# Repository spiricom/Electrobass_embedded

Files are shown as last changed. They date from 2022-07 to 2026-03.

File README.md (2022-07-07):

# Electrobass_embedded
Code for the three microcontrollers in the Electrobass hardware

## Changing name of an STMCube32 project 
https://community.st.com/s/question/0D53W000004Htp3SAC/change-the-name-of-the-project-in-stm32cubeide

1. Change name in `.project` file
2. Change directory name 
3. File->Import->existing project into workspace
4. click copy projects into workspace

## Adding LEAF after pull
1. right-click the leaf folder in the STMCube32IDE and go to properties (leaf->properties)
2. Under C/C++ Build->settings unclick `Exclude resource from build`
3. right-click the top level project and go to properties (project->properties)
3. Under C/C++ Build->settings->MCU GCC Compiler->Include Paths Add your leaf directory

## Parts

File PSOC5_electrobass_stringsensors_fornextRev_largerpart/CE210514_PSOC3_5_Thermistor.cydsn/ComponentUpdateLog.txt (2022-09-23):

Last Modified Date & Time: 07/15/2018 13:28:18

CE210514_PSOC3_5_Thermistor: CE210514_PSOC3_5_Thermistor.cydwr
	cy_boot [v5.20] to [v5.70]
	Em_EEPROM_Dynamic [v2.0] to [v2.10]
	LIN_Dynamic [v3.20] to [v4.0]

CE210514_PSOC3_5_Thermistor: TopDesign.cysch
	ADC [v3.20] to [v3.30]
	LCD [v2.10] to [v2.20]
	TX [v2.10] to [v2.20]
	Vhi [v2.10] to [v2.20]
	Vlow [v2.10] to [v2.20]
	Vtherm [v2.10] to [v2.20]

Last Modified Date & Time: 08/16/2022 14:56:38

CE210514_PSOC3_5_Thermistor: CE210514_PSOC3_5_Thermistor.cydwr
	cy_boot [v5.70] to [v6.10]
	Em_EEPROM_Dynamic [v2.10] to [v2.20]
	LIN_Dynamic [v4.0] to [v5.0]

CE210514_PSOC3_5_Thermistor: TopDesign.cysch
	Sleep_isr [v1.70] to [v1.71]

Last Modified Date & Time: 09/15/2022 13:51:09

CE210514_PSOC3_5_Thermistor: CE210514_PSOC3_5_Thermistor.cydwr
	LIN_Dynamic [v5.0] to [v6.0]

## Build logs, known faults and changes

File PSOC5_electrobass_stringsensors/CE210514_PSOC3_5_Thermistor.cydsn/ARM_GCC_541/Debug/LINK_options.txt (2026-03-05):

-Wl,--start-group -o "C:\\Users\\ggg88\\dev\\Electrobass_embedded\\PSOC5_electrobass_stringsensors\\CE210514_PSOC3_5_Thermistor.cydsn\\ARM_GCC_541\\Debug\\CE210514_PSOC3_5_Thermistor.elf" ".\\ARM_GCC_541\\Debug\\main.o" ".\\ARM_GCC_541\\Debug\\midi.o" ".\\ARM_GCC_541\\Debug\\oled.o" ".\\ARM_GCC_541\\Debug\\ssd1306.o" ".\\ARM_GCC_541\\Debug\\gfx.o" ".\\ARM_GCC_541\\Debug\\gfx_font.o" ".\\ARM_GCC_541\\Debug\\cyfitter_cfg.o" ".\\ARM_GCC_541\\Debug\\cymetadata.o" ".\\ARM_GCC_541\\Debug\\Cm3Start.o" ".\\ARM_GCC_541\\Debug\\CE210514_PSOC3_5_Thermistor.a" "C:\\Program\ Files\ (x86)\\Cypress\\PSoC\ Creator\\4.4\\PSoC\ Creator\\psoc\\content\\CyComponentLibrary\\CyComponentLibrary.cylib\\CapSense_CSD_v3_50\\Library\\CapSenseLibrary_GCC.a" "C:\\Program\ Files\ (x86)\\Cypress\\PSoC\ Creator\\4.4\\PSoC\ Creator\\psoc\\content\\cycomponentlibrary\\CyComponentLibrary.cylib\\CortexM3\\ARM_GCC_541\\Debug\\CyComponentLibrary.a" -mcpu=cortex-m3 -mthumb -l m -L "Generated_Source\\PSoC5" "-Wl,-Map,.\\ARM_GCC_541\\Debug/CE210514_PSOC3_5_Thermistor.map" -T "Generated_Source\\PSoC5\\cm3gcc.ld" -specs=nano.specs -Wl,--gc-sections -u_printf_float -g -ffunction-sections -finline-functions -O3 -flto -ffat-lto-objects -Wl,--end-group

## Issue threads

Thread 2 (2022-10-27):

change all leaf MB oscillators to use the distributed computing rather than block, and maybe switch oscillators to be wavetable unless synced

spiricom, 2022-10-27:

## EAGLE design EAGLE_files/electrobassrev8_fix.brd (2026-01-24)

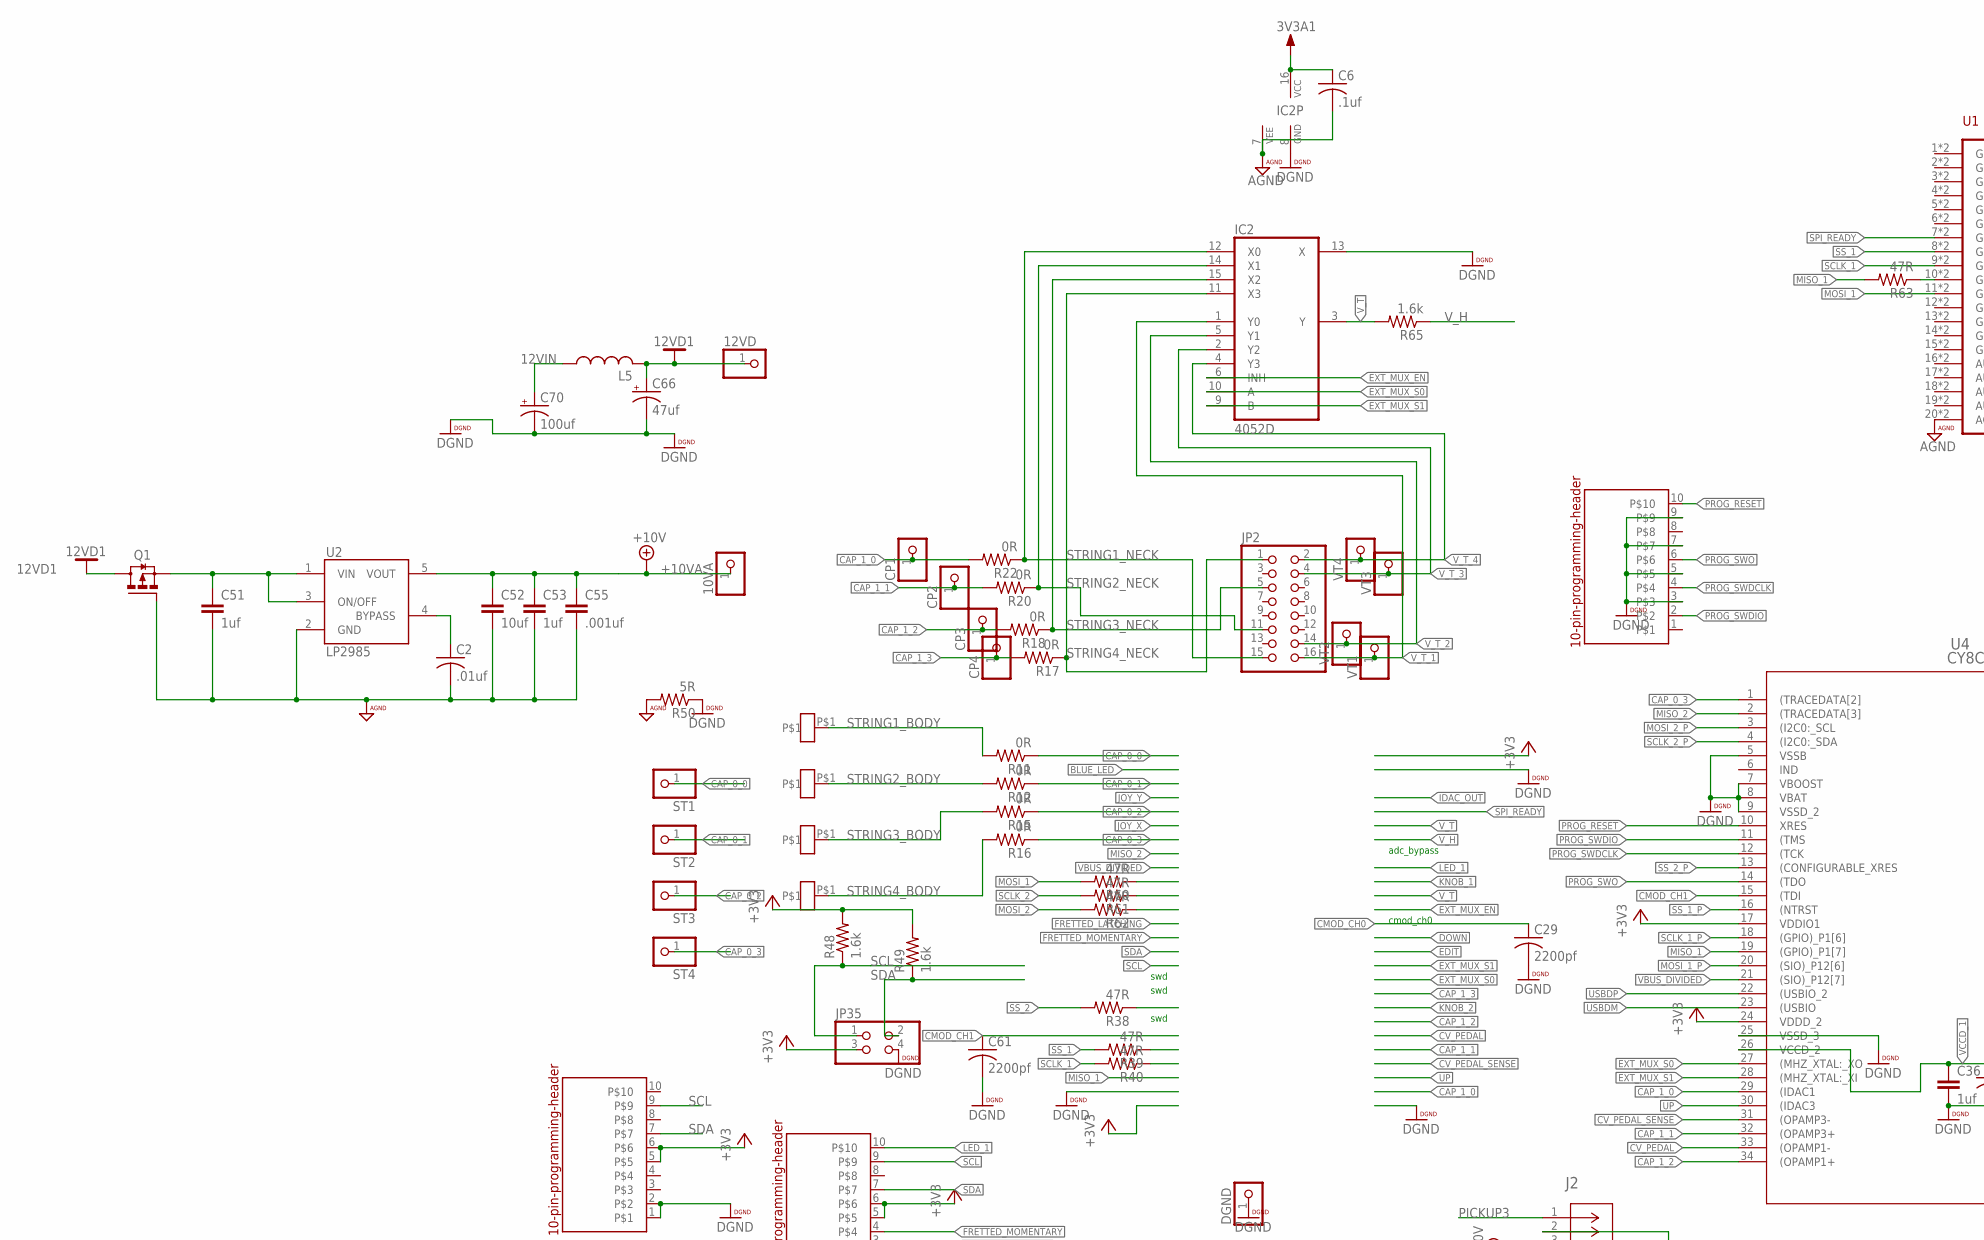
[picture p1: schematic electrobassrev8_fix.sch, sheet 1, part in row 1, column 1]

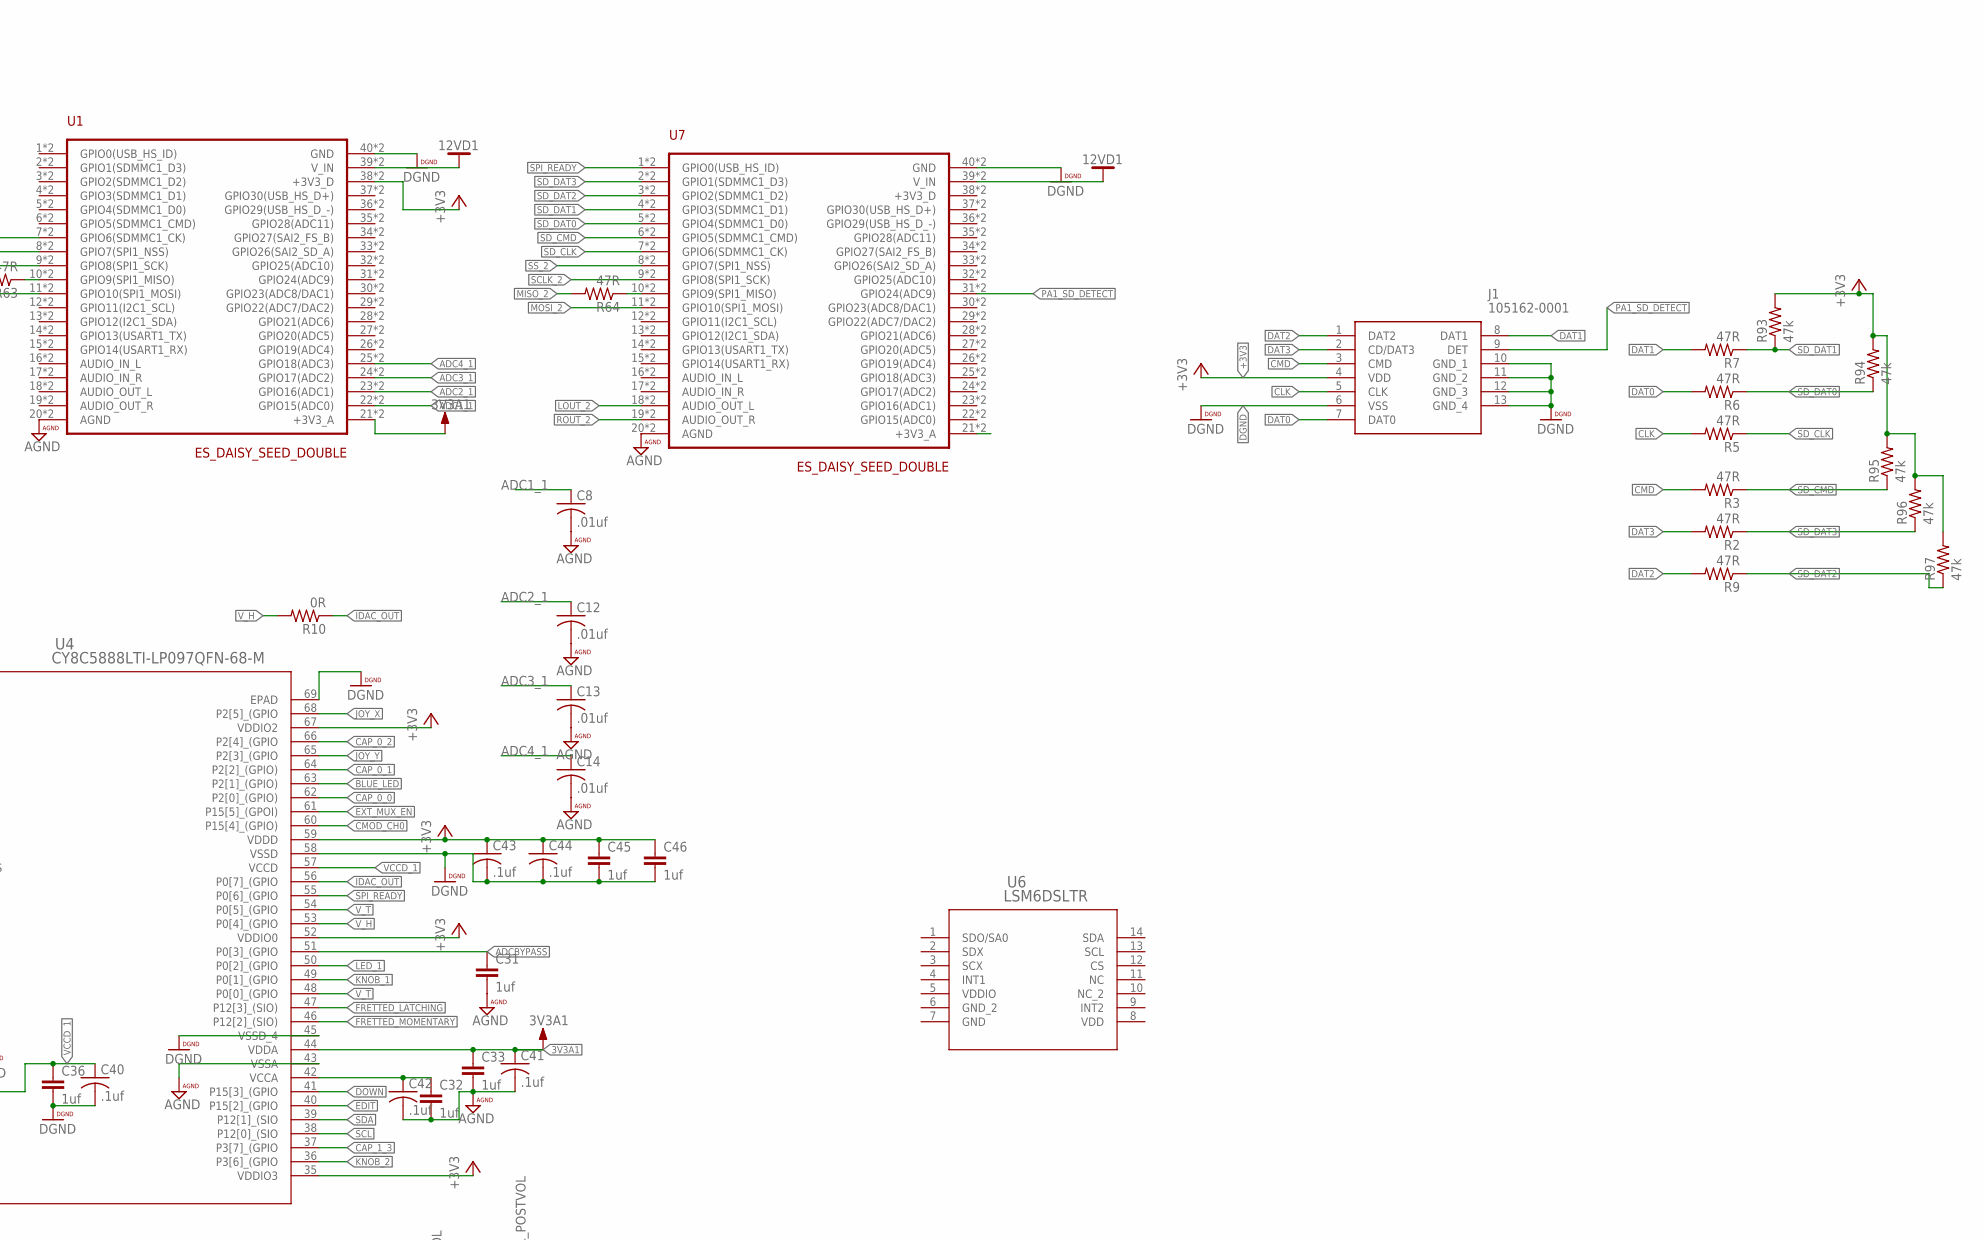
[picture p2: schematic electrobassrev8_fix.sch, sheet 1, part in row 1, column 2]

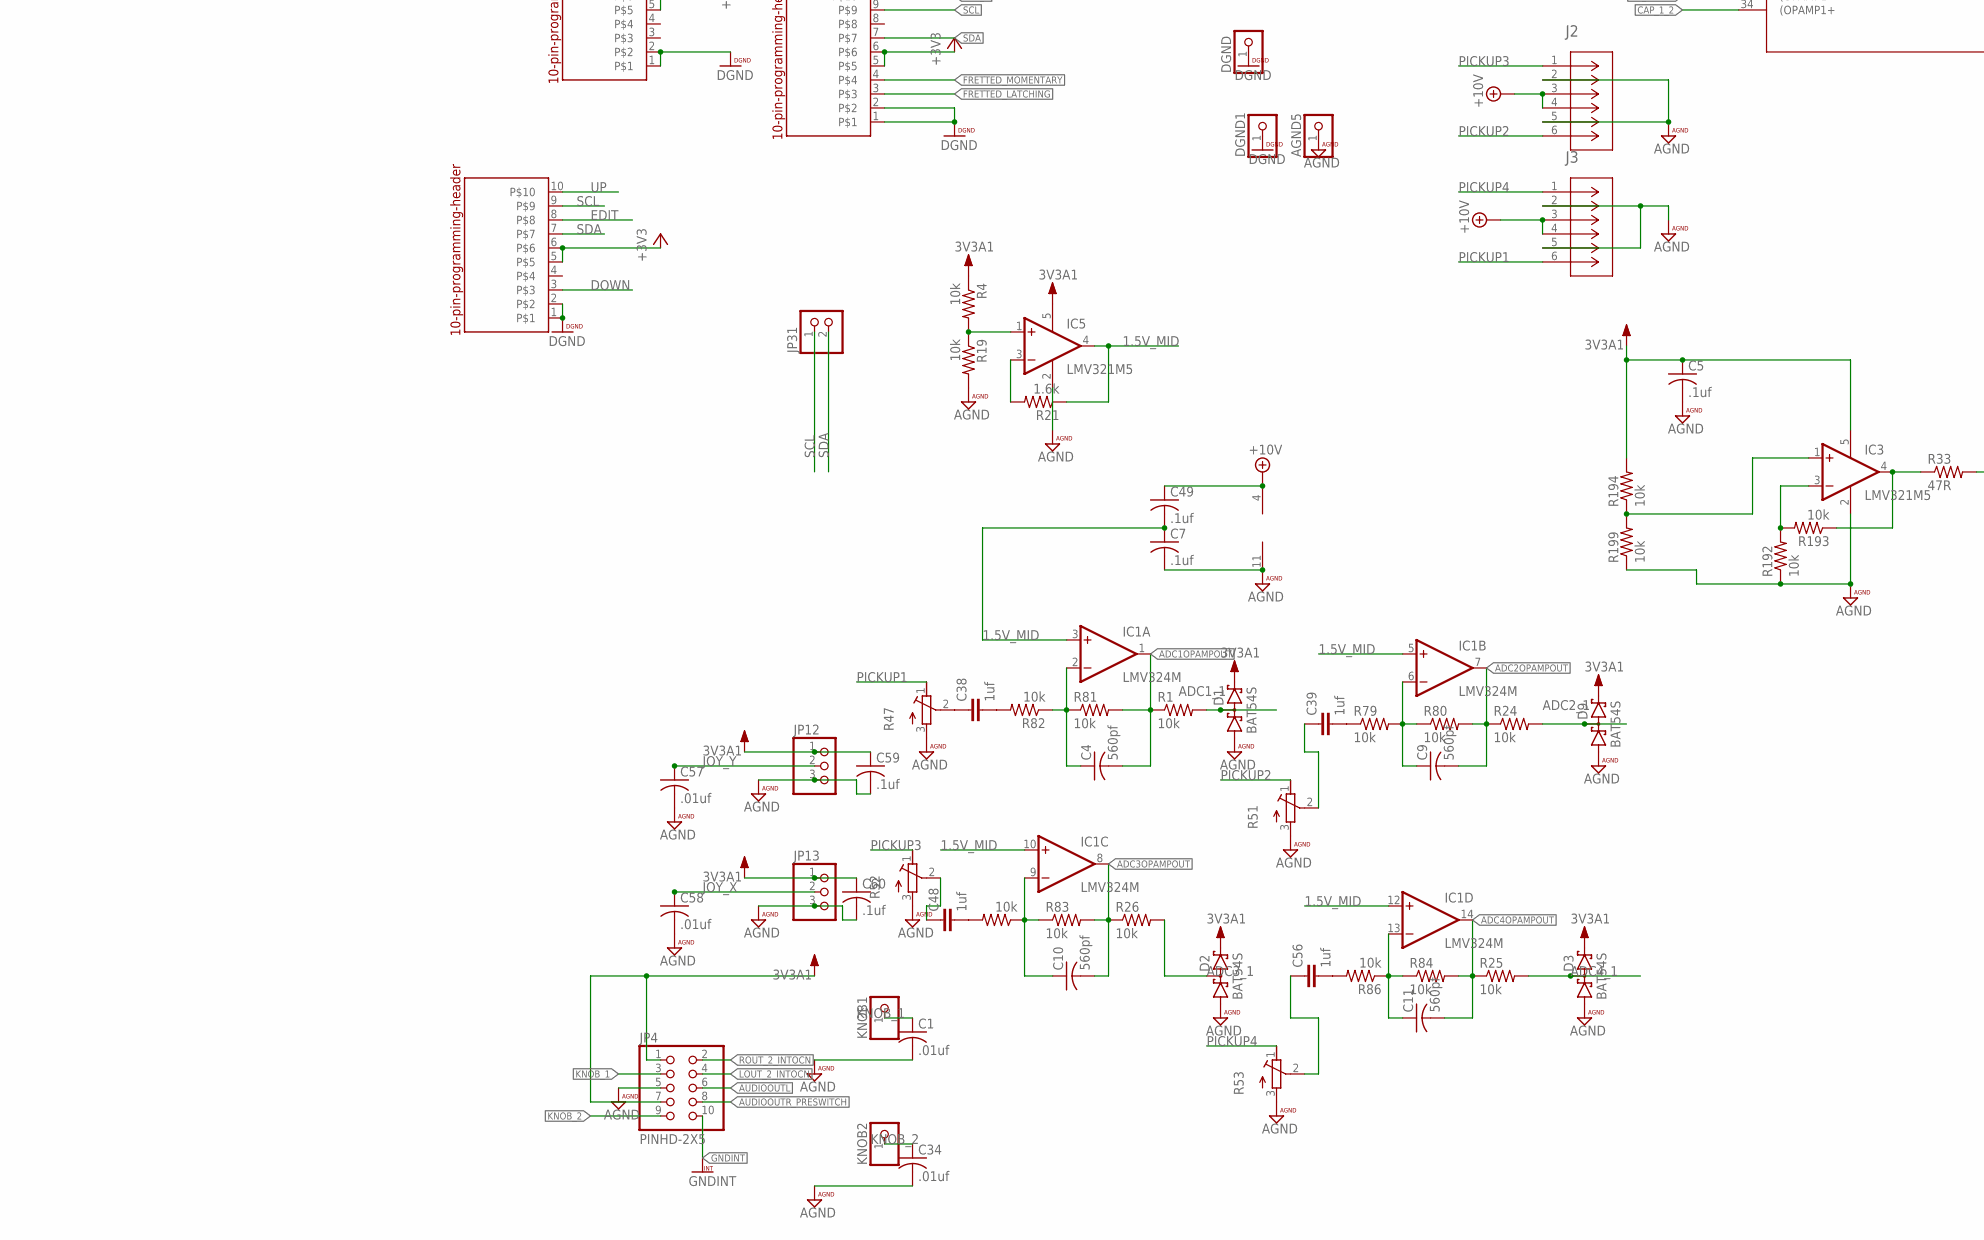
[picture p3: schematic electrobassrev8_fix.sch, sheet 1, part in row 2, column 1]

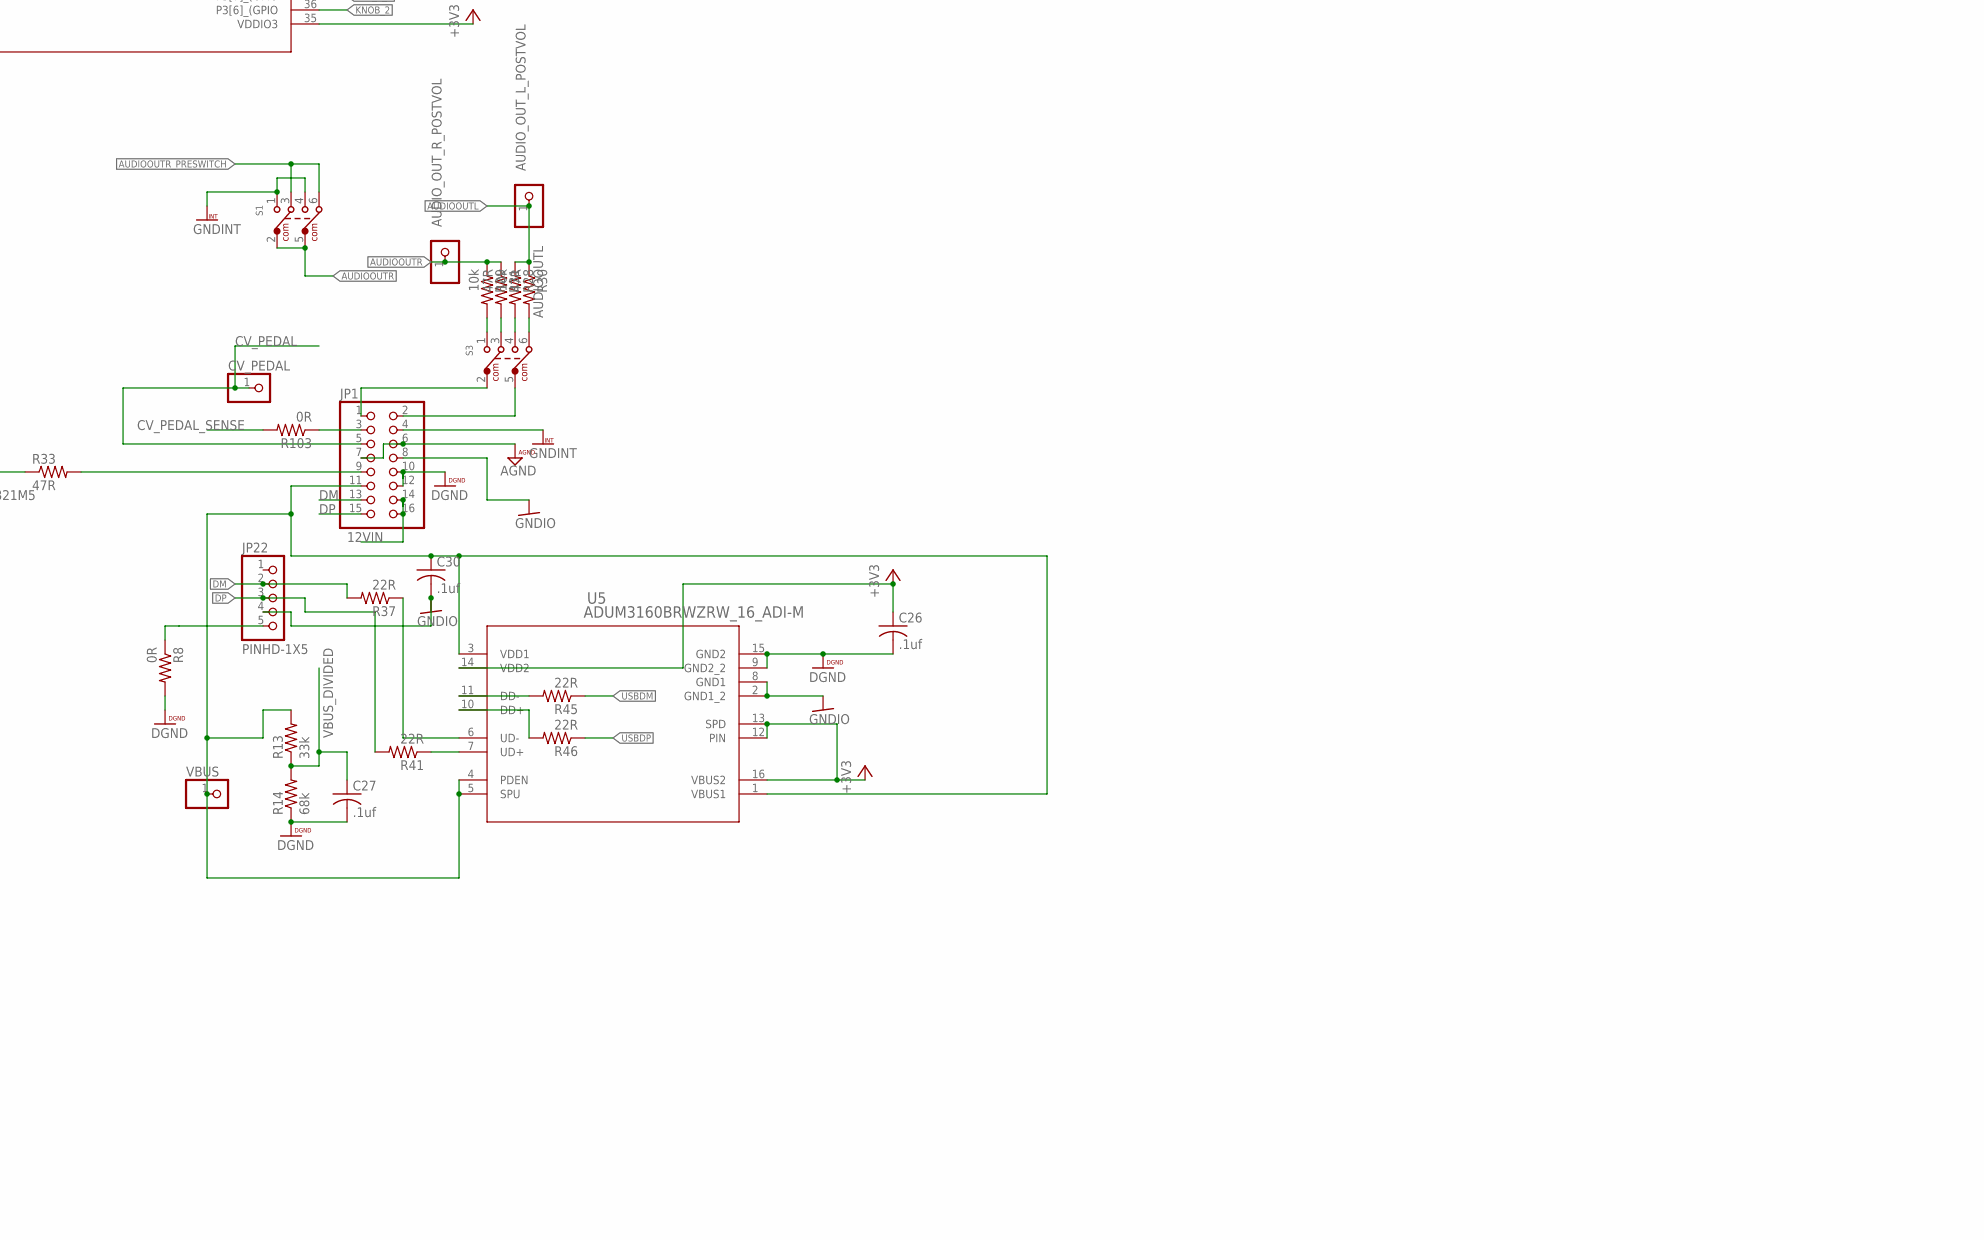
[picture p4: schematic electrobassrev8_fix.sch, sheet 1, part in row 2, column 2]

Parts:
10VA, 12VD: PINHD-1X1; 1X01; PARTNO *DNP
AGND5: PINHD-1X1; 1X01; PARTNO *DNP
AUDIO_OUT_L_POSTVOL: PINHD-1X1; 1X01; PARTNO *DNP
AUDIO_OUT_R_POSTVOL: PINHD-1X1; 1X01; PARTNO *DNP
C1, C2, C8, C12, C13, C14, C34, C57, C58: .01uf; C0603K; PARTNO CC0603KRX7R8BB103
C4, C9, C10, C11: 560pf; C0603K; PARTNO CC0603KRX7R8BB103
C5, C6, C7, C26, C27, C30, C40, C41, C42, C43, C44, C49, C59, C60: .1uf; C0603K; PARTNO CC0603KRX7R8BB104
C29, C61: 2200pf; C0603K; PARTNO CC0603KRX7R9BB222
C31, C32, C33, C36, C38, C39, C45, C46, C48, C51, C53, C56: 1uf; C0603; PARTNO UMK107BJ105KA-T
C52: 10uf; C1206K; PARTNO TMK316F106ZL-T
C55: .001uf; C0603; PARTNO CC0603JRNPO8BN102
C66: 47uf; PANASONIC_E; PARTNO EEE-1VA470P
C70: 100uf; PANASONIC_F; PARTNO UUQ1E101MCL1GS
CP1, CP2, CP3, CP4: PINHD-1X1; 1X01; PARTNO *DNP
CV_PEDAL: PINHD-1X1; 1X01; PARTNO *DNP
D1, D2, D3, D9: BAT54S; SOT23; PARTNO BAT54S-HF
DGND, DGND1: PINHD-1X1; 1X01; PARTNO *DNP
IC1: LMV324M; SO14
IC2: 4052D; SO16; PARTNO MC74HC4052ADR2G
IC3, IC5: LMV321M5; SOT23-5; PARTNO NCV20091SN3T1G
J1: 105162-0001; PARTNO 1051620001
J2, J3: SM06B-SRSS-TB(LF)(SN); CONN_SM06B-SRSS-TB_JST
JP1, JP2: PINHD-2X8; 2X08; PARTNO SBH11-PBPC-D08-ST-BK
JP4: PINHD-2X5; 2X05; PARTNO 3020-10-0100-00
JP5, JP8, JP9, JP23: 20021121; PARTNO 3221-10-0300-00
JP12, JP13: PINHD-1X3; 1X03; PARTNO *DNP
JP22: PINHD-1X5; 1X05; PARTNO *DNP
JP31: PINHD-1X2; 1X02; PARTNO *DNP
JP35: PINHD-2X2; 2X02; PARTNO *DNP
KNOB1, KNOB2: PINHD-1X1; 1X01; PARTNO *DNP
L5: L-US6000-XXX-RC; 6000-XXXX-RC; PARTNO RLB9012-100KL
Q1: DMP3099L; SUPER-SOT3; PARTNO DMP3125L-7
R1, R24, R25, R26, R80, R81, R83, R84: 10k; R0603; PARTNO ESR03EZPF2002
R2, R3, R5, R6, R7, R9, R30, R31, R33, R38, R39, R40, R60, R61, R62, R63, R64: 47R; R0603; PARTNO RC0603JR-0747RL
R4, R19, R28, R29, R79, R82, R85, R86, R192, R193, R194, R199: 10k; R0603; PARTNO ESR03EZPF1002
R8, R10, R11, R12, R15, R16, R17, R18, R20, R22, R103: 0R; R0603; PARTNO CRCW06030000Z0EAHP
R13: 33k; R0603; PARTNO ESR03EZPJ333
R14: 68k; R0603; PARTNO CRCW060368K0FKEAHP
R21, R48, R49, R65: 1.6k; R0603; PARTNO ESR03EZPJ152
R37, R41, R45, R46: 22R; R0603; PARTNO RC0603JR-0747RL
R47, R51, R52, R53: R-TRIMM3314J; RTRIM3314J
R50: 5R; R0603; PARTNO CRCW06030000Z0EAHP
R93, R94, R95, R96, R97: 47k; R0603; PARTNO ESR03EZPJ333
S1, S3: 452404020202; PARTNO 452404020202
ST1, ST2, ST3, ST4: PINHD-1X1; 1X01; PARTNO *DNP
U1, U7: ES_DAISY_SEED_DOUBLE; PARTNO *DNP
U2: LP2985; SOT25; PARTNO LP2985-10DBVR
U4: CY8C5888LTI-LP097QFN-68-M; QFN-68-M
U5: ADUM3160BRWZRW_16_ADI-M; RW_16_ADI-M
U6: LSM6DSLTR; QFN_6DSLTR_STM
U$15, U$16, U$68, U$69: STRING_HOLDER; PARTNO *DNP
VBUS: PINHD-1X1; 1X01; PARTNO *DNP
VT1, VT2, VT3, VT4: PINHD-1X1; 1X01; PARTNO *DNP

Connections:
1.5V_MID: C7.1, C49.2, IC1.3 (+IN), IC1.5 (+IN), IC1.10 (+IN), IC1.12 (+IN), IC5.4 (OUT), R21.1
3V3A1: C5.1, C6.1, C33.1, C41.1, C59.1, C60.1, D1.2 (C2), D2.2 (C2), D3.2 (C2), D9.2 (C2), IC2.16 (VCC), IC3.5 (V+), IC5.5 (V+), JP4.1, JP4.7, JP12.1, JP13.1, R4.1, R194.2, U1.21 (+3V3_A), U1.B21 (+3V3_A), U4.44 (VDDA)
3V3FORPEDAL: JP1.9, R33.2
12VD1: 12VD.1, C66.+, L5.2, Q1.3 (D), U1.39 (V_IN), U1.B39 (V_IN), U7.39 (V_IN), U7.B39 (V_IN); also elsewhere on the board
12VIN: C70.+, JP1.14, JP1.16, L5.1
+3V3: C26.1, C43.1, C44.1, C45.1, C46.1, J1.4 (VDD), JP8.5, JP8.6, JP9.5, JP9.6, JP23.5, JP23.6, JP35.3, R48.2, R49.2, R93.2, R94.2, R95.2, R96.2, R97.2, U1.38 (+3V3_D), U1.B38 (+3V3_D), U4.17 (VDDIO1), U4.24 (VDDD_2), U4.35 (VDDIO3), U4.52 (VDDIO0), U4.59 (VDDD), U4.67 (VDDIO2), U5.12 (PIN), U5.13 (SPD), U5.14 (VDD2), U5.16 (VBUS2)
+10V: 10VA.1, C49.1, C52.1, C53.1, C55.1, IC1.4 (V+), J2.3, J2.4, J3.3, J3.4, U2.5 (VOUT)
ADC1OPAMPOUT: C4.2, IC1.1 (OUT), R1.1, R81.2
ADC1_1: C8.1, D1.3 (C1A2), R1.2, U1.22 (GPIO15(ADC0)), U1.B22 (GPIO15(ADC0))
ADC2OPAMPOUT: C9.2, IC1.7 (OUT), R24.1, R80.2
ADC2_1: C12.1, D9.3 (C1A2), R24.2, U1.23 (GPIO16(ADC1)), U1.B23 (GPIO16(ADC1))
ADC3OPAMPOUT: C10.2, IC1.8 (OUT), R26.1, R83.2
ADC3_1: C13.1, D2.3 (C1A2), R26.2, U1.24 (GPIO17(ADC2)), U1.B24 (GPIO17(ADC2))
ADC4OPAMPOUT: C11.2, IC1.14 (OUT), R25.1, R84.2
ADC4_1: C14.1, D3.3 (C1A2), R25.2, U1.25 (GPIO18(ADC3)), U1.B25 (GPIO18(ADC3))
ADCBYPASS: C31.1, U4.51 (P0[3]_(GPIO)
AGND: AGND5.1, C1.2, C2.2, C5.2, C6.2, C7.2, C8.2, C12.2, C13.2, C14.2, C31.2, C32.2, C33.2, C34.2, C41.2, C42.2, C51.2, C52.2, C53.2, C55.2, C57.2, C58.2, C59.2, C60.2, D1.1 (A1), D2.1 (A1), D3.1 (A1), D9.1 (A1), IC1.11 (V-), IC2.7 (VEE), IC3.2 (V-), IC5.2 (V-), J2.2, J2.5, J3.2, J3.5, JP1.6, JP1.7, JP4.5, JP12.3, JP13.3, Q1.1 (G), R19.2, R47.3 (A), R50.2, R51.3 (A), R52.3 (A), R53.3 (A), R192.1, R199.1, U1.20 (AGND), U1.B20 (AGND), U2.2 (GND), U4.43 (VSSA), U7.20 (AGND), U7.B20 (AGND); also elsewhere on the board
AUDIOOUTL: AUDIO_OUT_L_POSTVOL.1, JP4.6, R28.1, R30.1
AUDIOOUTR: AUDIO_OUT_R_POSTVOL.1, R29.1, R31.1, S1.2 (COM), S1.5 (COM1)
AUDIOOUTR_PRESWITCH: JP4.8, S1.3, S1.6
BLUE_LED: U4.63 (P2[1]_(GPIO))
BYPASS: C2.1, U2.4 (BYPASS)
CAP_0_0: R11.1, ST1.1, U4.62 (P2[0]_(GPIO))
CAP_0_1: R12.1, ST2.1, U4.64 (P2[2]_(GPIO))
CAP_0_2: R15.1, ST3.1, U4.66 (P2[4]_(GPIO)
CAP_0_3: R16.1, ST4.1, U4.1 ((TRACEDATA[2])
CAP_1_0: CP1.1, R22.2, U4.29 ((IDAC1)
CAP_1_1: CP2.1, R20.2, U4.32 ((OPAMP3+)
CAP_1_2: CP3.1, R18.2, U4.34 ((OPAMP1+)
CAP_1_3: CP4.1, R17.2, U4.37 (P3[7]_(GPIO)
CLK: J1.5 (CLK), R5.2
CMD: J1.3 (CMD), R3.2
CMOD_CH0: C29.1, U4.60 (P15[4]_(GPIO))
CMOD_CH1: C61.1, U4.15 ((TDI)
CV_PEDAL: CV_PEDAL.1, JP1.5, U4.33 ((OPAMP1-)
CV_PEDAL_SENSE: R103.2, U4.31 ((OPAMP3-)
DAT0: J1.7 (DAT0), R6.2
DAT1: J1.8 (DAT1), R7.2
DAT2: J1.1 (DAT2), R9.2
DAT3: J1.2 (CD/DAT3), R2.2
DGND: C26.2, C27.2, C29.2, C36.2, C40.2, C43.2, C44.2, C45.2, C46.2, C61.2, C66.-, C70.-, DGND.1, DGND1.1, IC2.8 (GND), IC2.13 (X), J1.6 (VSS), J1.10 (GND_1), J1.11 (GND_2), J1.12 (GND_3), J1.13 (GND_4), JP1.10, JP1.12, JP5.3, JP5.5, JP5.7, JP5.9, JP8.1, JP8.2, JP9.1, JP9.2, JP23.1, JP23.2, JP35.4, R8.2, R14.1, R50.1, U1.40 (GND), U1.B40 (GND), U4.5 (VSSB), U4.7 (VBOOST), U4.8 (VBAT), U4.9 (VSSD_2), U4.25 (VSSD_3), U4.45 (VSSD_4), U4.58 (VSSD), U4.69 (EPAD), U5.9 (GND2_2), U5.15 (GND2), U7.40 (GND), U7.B40 (GND)
DM: JP1.13, JP22.2, R37.2
DOWN: JP9.3, U4.41 (P15[3]_(GPIO)
DP: JP1.15, JP22.3, R41.2
EDIT: JP9.8, U4.40 (P15[2]_(GPIO)
EXT_MUX_EN: IC2.6 (INH), U4.61 (P15[5]_(GPOI))
EXT_MUX_S0: IC2.10 (A), U4.27 ((MHZ_XTAL:_XO)
EXT_MUX_S1: IC2.9 (B), U4.28 ((MHZ_XTAL:_XI)
FRETTED_LATCHING: JP23.3, U4.47 (P12[3]_(SIO))
FRETTED_MOMENTARY: JP23.4, U4.46 (P12[2]_(SIO))
GND: U6.7 (GND)
GNDINT: JP1.4, JP4.10; also elsewhere on the board
GNDIO: C30.2, JP1.8, JP22.4, U5.2 (GND1_2), U5.8 (GND1)
GND_2: U6.6 (GND_2)
IDAC_OUT: R10.1, U4.56 (P0[7]_(GPIO)
JOY_X: C58.1, JP13.2, U4.68 (P2[5]_(GPIO)
JOY_Y: C57.1, JP12.2, U4.65 (P2[3]_(GPIO)
KNOB_1: C1.1, JP4.3, KNOB1.1, U4.49 (P0[1]_(GPIO)
KNOB_2: C34.1, JP4.9, KNOB2.1, U4.36 (P3[6]_(GPIO)
LED_1: JP23.10, U4.50 (P0[2]_(GPIO)
LOUT_2: U7.18 (AUDIO_OUT_L), U7.B18 (AUDIO_OUT_L); also elsewhere on the board
LOUT_2_INTOCN: JP4.4; also elsewhere on the board
MISO_1: R63.2, U4.19 ((GPIO)_P1[7])
MISO_1_P: R63.1, U1.10 (GPIO9(SPI1_MISO)), U1.B10 (GPIO9(SPI1_MISO))
MISO_2: R64.2, U4.2 ((TRACEDATA[3])
MISO_2_P: R64.1, U7.10 (GPIO9(SPI1_MISO)), U7.B10 (GPIO9(SPI1_MISO))
MOSI_1: R60.2, U1.11 (GPIO10(SPI1_MOSI)), U1.B11 (GPIO10(SPI1_MOSI))
MOSI_1_P: R60.1, U4.20 ((SIO)_P12[6])
MOSI_2: R62.2, U7.11 (GPIO10(SPI1_MOSI)), U7.B11 (GPIO10(SPI1_MOSI))
MOSI_2_P: R62.1, U4.3 ((I2C0:_SCL)
unnamed: JP1.3, R103.1
unnamed: R29.2, S3.1
unnamed: R28.2, S3.4
unnamed: JP1.1, S3.2 (COM)
unnamed: JP1.2, S3.5 (COM1)
unnamed: R31.2, S3.3
unnamed: R30.2, S3.6
unnamed: IC3.4 (OUT), R33.1, R193.1
unnamed: JP22.5, R8.1
unnamed: C38.2, R82.2
unnamed: S1.1, S1.4
unnamed: C39.2, R79.1
unnamed: R37.1, U5.6 (UD-)
unnamed: R41.1, U5.7 (UD+)
unnamed: C48.2, R85.2
unnamed: C56.2, R86.2
unnamed: C4.1, IC1.2 (-IN), R81.1, R82.1
unnamed: C9.1, IC1.6 (-IN), R79.2, R80.1
unnamed: C11.1, IC1.13 (-IN), R84.1, R86.1
unnamed: C10.1, IC1.9 (-IN), R83.1, R85.1
unnamed: IC5.3 (-IN), R21.2
unnamed: IC5.1 (+IN), R4.2, R19.1
unnamed: U7.21 (+3V3_A), U7.B21 (+3V3_A)
unnamed: C48.1, R52.2 (S)
unnamed: R45.2, U5.11 (DD-)
unnamed: R46.2, U5.10 (DD+)
unnamed: C56.1, R53.2 (S)
unnamed: C38.1, R47.2 (S)
unnamed: C39.1, R51.2 (S)
unnamed: C51.1, Q1.2 (S), U2.1 (VIN), U2.3 (ON/OFF)
unnamed: IC3.3 (-IN), R192.2, R193.2
unnamed: IC3.1 (+IN), R194.1, R199.2
PA1_SD_DETECT: J1.9 (DET), U7.31 (GPIO24(ADC9)), U7.B31 (GPIO24(ADC9))
PICKUP1: J3.6, R47.1 (E)
PICKUP2: J2.6, R51.1 (E)
PICKUP3: J2.1, R52.1 (E)
PICKUP4: J3.1, R53.1 (E)
PROG_RESET: JP5.10, U4.10 (XRES)
PROG_SWDCLK: JP5.4, U4.12 ((TCK)
PROG_SWDIO: JP5.2, U4.11 ((TMS)
PROG_SWO: JP5.6, U4.14 ((TDO)
ROUT_2: U7.19 (AUDIO_OUT_R), U7.B19 (AUDIO_OUT_R); also elsewhere on the board
ROUT_2_INTOCN: JP4.2; also elsewhere on the board
SCL: JP8.9, JP9.9, JP23.9, JP31.1, JP35.1, R48.1, U4.38 (P12[0]_(SIO)
SCLK_1: R40.2, U1.9 (GPIO8(SPI1_SCK)), U1.B9 (GPIO8(SPI1_SCK))
SCLK_1_P: R40.1, U4.18 ((GPIO)_P1[6])
SCLK_2: R61.2, U7.9 (GPIO8(SPI1_SCK)), U7.B9 (GPIO8(SPI1_SCK))
SCLK_2_P: R61.1, U4.4 ((I2C0:_SDA)
SDA: JP8.7, JP9.7, JP23.7, JP31.2, JP35.2, R49.1, U4.39 (P12[1]_(SIO)
SD_CLK: R5.1, U7.7 (GPIO6(SDMMC1_CK)), U7.B7 (GPIO6(SDMMC1_CK))
SD_CMD: R3.1, R95.1, U7.6 (GPIO5(SDMMC1_CMD)), U7.B6 (GPIO5(SDMMC1_CMD))
SD_DAT0: R6.1, R94.1, U7.5 (GPIO4(SDMMC1_D0)), U7.B5 (GPIO4(SDMMC1_D0))
SD_DAT1: R7.1, R93.1, U7.4 (GPIO3(SDMMC1_D1)), U7.B4 (GPIO3(SDMMC1_D1))
SD_DAT2: R9.1, R97.1, U7.3 (GPIO2(SDMMC1_D2)), U7.B3 (GPIO2(SDMMC1_D2))
SD_DAT3: R2.1, R96.1, U7.2 (GPIO1(SDMMC1_D3)), U7.B2 (GPIO1(SDMMC1_D3))
SPI_READY: U1.7 (GPIO6(SDMMC1_CK)), U1.B7 (GPIO6(SDMMC1_CK)), U4.55 (P0[6]_(GPIO), U7.1 (GPIO0(USB_HS_ID)), U7.B1 (GPIO0(USB_HS_ID))
SS_1: R39.2, U1.8 (GPIO7(SPI1_NSS)), U1.B8 (GPIO7(SPI1_NSS))
SS_1_P: R39.1, U4.16 ((NTRST)
SS_2: R38.2, U7.8 (GPIO7(SPI1_NSS)), U7.B8 (GPIO7(SPI1_NSS))
SS_2_P: R38.1, U4.13 ((CONFIGURABLE_XRES)
STRING1_BODY: R11.2, U$16.P$1
STRING1_NECK: IC2.12 (X0), JP2.15, R22.1
STRING2_BODY: R12.2, U$15.P$1
STRING2_NECK: IC2.14 (X1), JP2.11, R20.1
STRING3_BODY: R15.2, U$68.P$1
STRING3_NECK: IC2.15 (X2), JP2.5, R18.1
STRING4_BODY: R16.2, U$69.P$1
STRING4_NECK: IC2.11 (X3), JP2.1, R17.1
UP: JP9.10, U4.30 ((IDAC3)
USBDM: R45.1, U4.23 ((USBIO)
USBDP: R46.1, U4.22 ((USBIO_2)
VBUS: C30.1, JP1.11, R13.2, U5.1 (VBUS1), U5.3 (VDD1), U5.4 (PDEN), U5.5 (SPU), VBUS.1
VBUS_DIVIDED: C27.1, R13.1, R14.2, U4.21 ((SIO)_P12[7])
VCCA_1: C32.1, C42.1, U4.42 (VCCA)
VCCD_1: C36.1, C40.1, U4.26 (VCCD_2), U4.57 (VCCD)
VDD: U6.8 (VDD)
VDDIO: U6.5 (VDDIO)
V_H: R10.2, R65.1, U4.53 (P0[4]_(GPIO)
V_T: IC2.3 (Y), R65.2, U4.48 (P0[0]_(GPIO), U4.54 (P0[5]_(GPIO)
V_T_1: IC2.1 (Y0), JP2.16, VT1.1
V_T_2: IC2.5 (Y1), JP2.14, VT2.1
V_T_3: IC2.2 (Y2), JP2.4, VT3.1
V_T_4: IC2.4 (Y3), JP2.2, VT4.1

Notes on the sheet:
+10VA
cmod_ch0
swd
adc_bypass

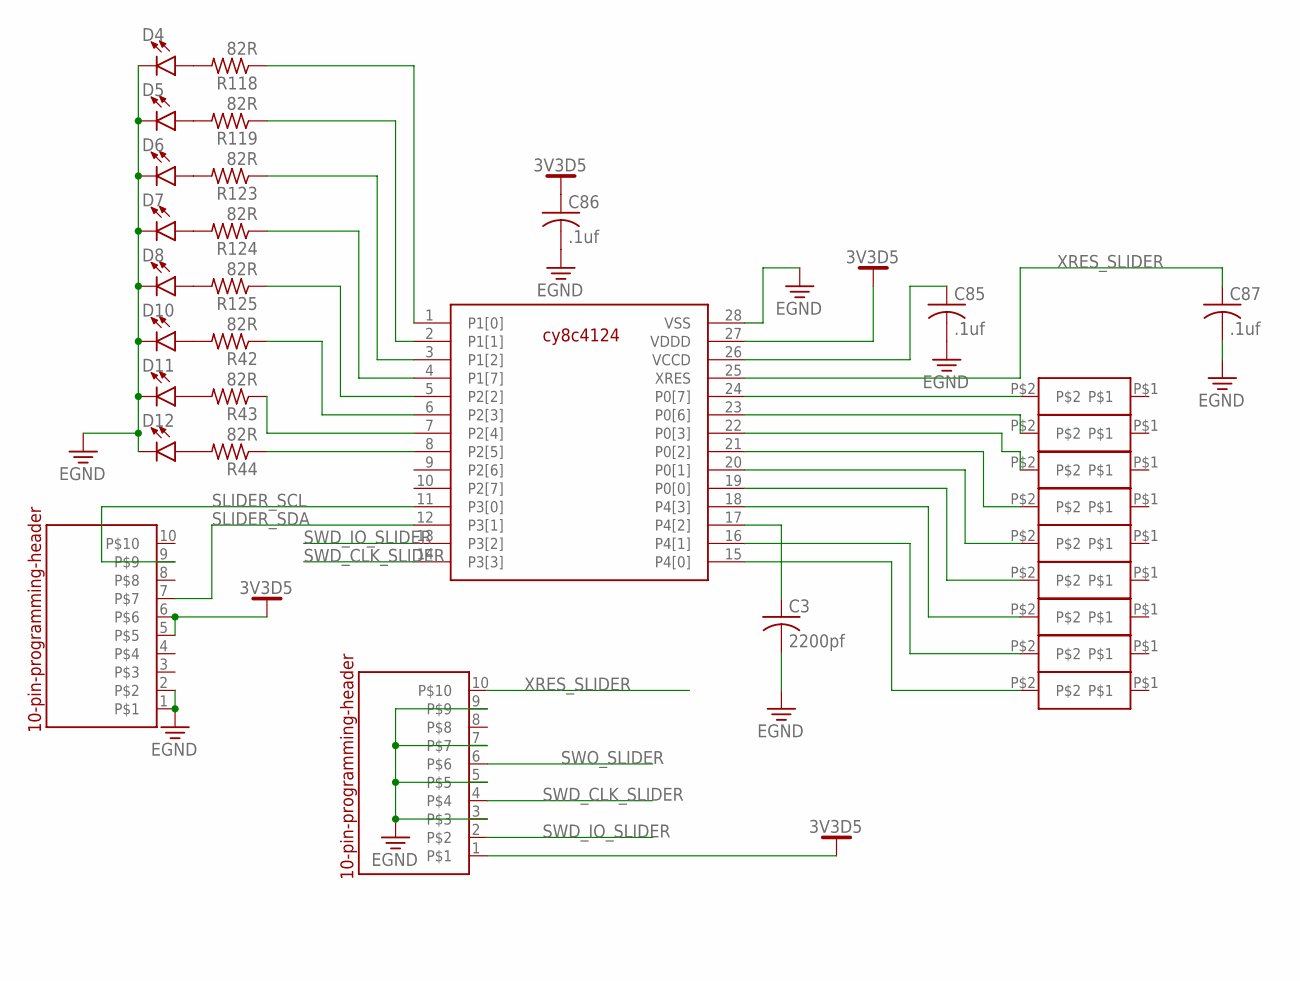
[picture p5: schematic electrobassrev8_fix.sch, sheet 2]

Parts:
C3: 2200pf; C0603K; PARTNO CC0603KRX7R9BB222
C85, C86, C87: .1uf; C0603K; PARTNO CC0603KRX7R8BB104
D4, D5, D6, D7, D8, D10, D11, D12: LED1206-BOTTOM; LED-1206-BOTTOM; PARTNO IN-S124BRA
IC18: CY8C4124; SSOP28; PARTNO CY8C4124PVI-432
JP6, JP34: 20021121; PARTNO 3221-10-0300-00
R42, R43, R44, R118, R119, R123, R124, R125: 82R; R0603; PARTNO RC0603JR-0782RL
U$1, U$5, U$11, U$12, U$13, U$14, U$18, U$19, U$20: SLIDER_SEGMENT; SLIDERS_SLIDER-SEGMENT3; PARTNO *DNP

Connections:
3V3D5: C86.1, IC18.27 (VDDD), JP6.5, JP6.6, JP34.1
EGND: C3.2, C85.2, C86.2, C87.2, D4.C, D5.C, D6.C, D7.C, D8.C, D10.C, D11.C, D12.C, IC18.28 (VSS), JP6.1, JP6.2, JP34.3, JP34.5, JP34.7, JP34.9
unnamed: D4.A, R118.2
unnamed: D5.A, R119.2
unnamed: D6.A, R123.2
unnamed: D7.A, R124.2
unnamed: D8.A, R125.2
unnamed: D10.A, R42.2
unnamed: D11.A, R43.2
unnamed: D12.A, R44.2
unnamed: IC18.8 (P2[5]), R44.1
unnamed: IC18.7 (P2[4]), R43.1
unnamed: IC18.6 (P2[3]), R42.1
unnamed: IC18.15 (P4[0]), U$20.P$2
unnamed: IC18.19 (P0[0]), U$14.P$2
unnamed: IC18.20 (P0[1]), U$13.P$2
unnamed: IC18.21 (P0[2]), U$12.P$2
unnamed: IC18.22 (P0[3]), U$11.P$2
unnamed: IC18.24 (P0[7]), U$1.P$2
unnamed: IC18.16 (P4[1]), U$19.P$2
unnamed: IC18.23 (P0[6]), U$5.P$2
unnamed: IC18.18 (P4[3]), U$18.P$2
unnamed: C85.1, IC18.26 (VCCD)
unnamed: IC18.1 (P1[0]), R118.1
unnamed: C3.1, IC18.17 (P4[2])
unnamed: IC18.2 (P1[1]), R119.1
unnamed: IC18.3 (P1[2]), R123.1
unnamed: IC18.4 (P1[7]), R124.1
unnamed: IC18.5 (P2[2]), R125.1
SLIDER_SCL: IC18.11 (P3[0]), JP6.9
SLIDER_SDA: IC18.12 (P3[1]), JP6.7
SWD_CLK_SLIDER: IC18.14 (P3[3]), JP34.4
SWD_IO_SLIDER: IC18.13 (P3[2]), JP34.2
SWO_SLIDER: JP34.6
XRES_SLIDER: C87.1, IC18.25 (XRES), JP34.10

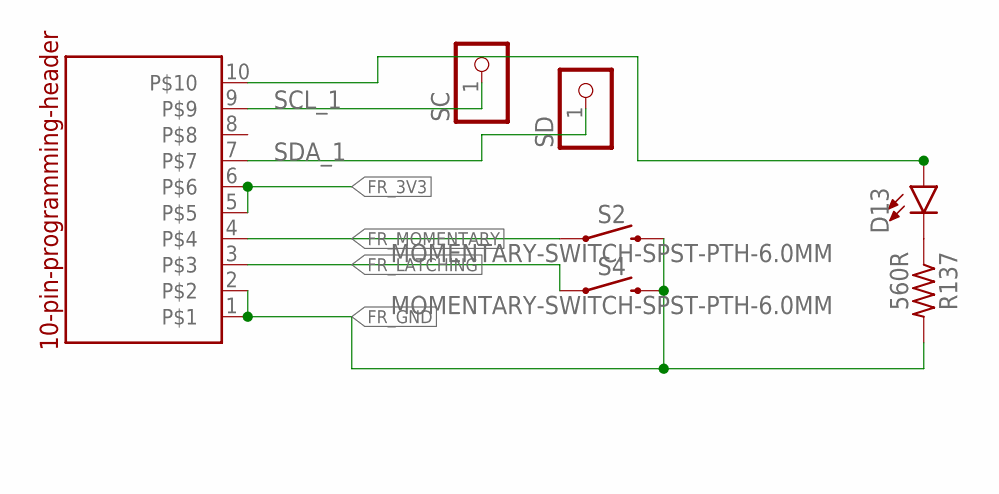
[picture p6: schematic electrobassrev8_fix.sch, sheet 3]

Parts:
D13: LED1206-BOTTOM; LED-1206-BOTTOM; PARTNO IN-S124BRA
JP24: 20021121; PARTNO 3221-10-0300-00
R137: 560R; R0603; PARTNO ESR03EZPF5600
S2, S4: MOMENTARY-SWITCH-SPST-PTH-6.0MM; TACTILE_SWITCH_PTH_6.0MM; PARTNO TL1105SPF160Q
SC: PINHD-1X1; 1X01; PARTNO *DNP
SD: PINHD-1X1; 1X01; PARTNO *DNP

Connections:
FR_3V3: JP24.5, JP24.6
FR_GND: JP24.1, JP24.2, R137.2, S2.3 (2), S4.3 (2)
FR_LATCHING: JP24.3, S4.1
FR_MOMENTARY: JP24.4, S2.1
unnamed: D13.A, JP24.10
unnamed: D13.C, R137.1
SCL_1: JP24.9, SC.1
SDA_1: JP24.7, SD.1

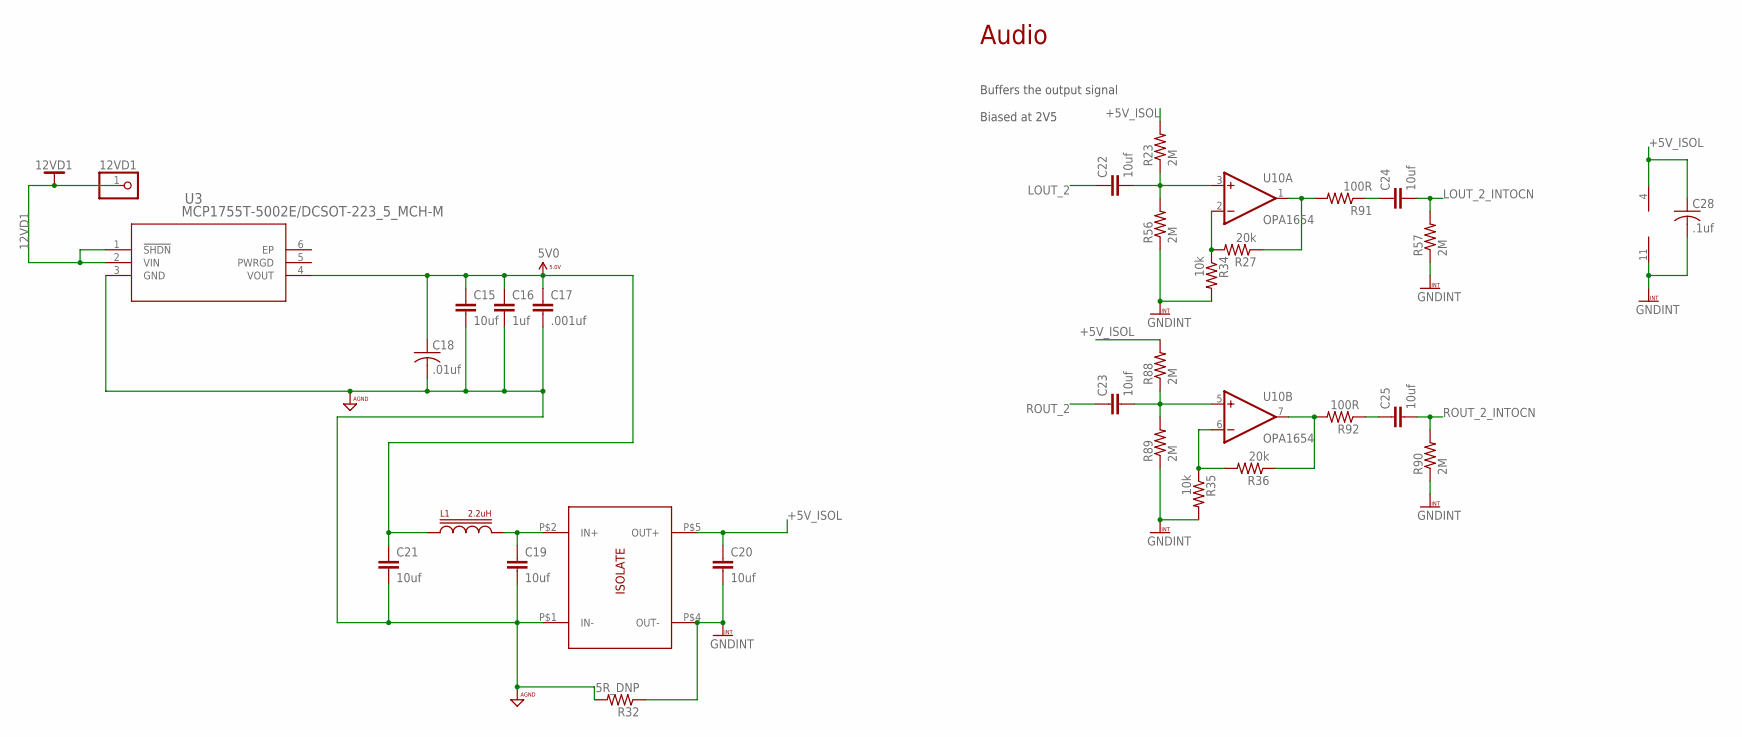
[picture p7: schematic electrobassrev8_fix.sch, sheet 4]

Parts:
12VD1: PINHD-1X1; 1X01; PARTNO *DNP
C15, C19, C20, C21, C22, C23, C24, C25: 10uf; C1206K; PARTNO TMK316F106ZL-T
C16: 1uf; C0603; PARTNO UMK107BJ105KA-T
C17: .001uf; C0603; PARTNO CC0603JRNPO8BN102
C18: .01uf; C0603K; PARTNO CC0603KRX7R8BB103
C28: .1uf; C0603K; PARTNO CC0603KRX7R8BB104
L1: 2.2uH; BOURNS_SRP2010
R23, R56, R57, R88, R89, R90: 2M; R0603
R27, R36: 20k; R0603; PARTNO ESR03EZPF1002
R32: 5R_DNP; R0603; PARTNO CRCW06030000Z0EAHP
R34, R35: 10k; R0603; PARTNO ESR03EZPF1002
R91, R92: 100R; R0603
U3: MCP1755T-5002E/DCSOT-223_5_MCH-M; SOT-223_5_MCH-M
U10: OPA1654; TSSOP-14
U$9: POWER_ISOLATE; XP_POWER_ISEXXXXA

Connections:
5V0: C15.1, C16.1, C17.1, C18.1, C21.1, L1.P$1, U3.4 (VOUT)
12VD1: 12VD1.1, U3.1 (!SHDN), U3.2 (VIN); also elsewhere on the board
+5V_ISOL: C20.1, C28.1, R23.2, R88.2, U10.4 (V+), U$9.P$5 (OUT+)
AGND: C15.2, C16.2, C17.2, C18.2, C19.2, C21.2, R32.2, U3.3 (GND), U$9.P$1 (IN-); also elsewhere on the board
GNDINT: C20.2, C28.2, R32.1, R34.2, R35.2, R56.1, R57.1, R89.1, R90.1, U10.11 (V-), U$9.P$4 (OUT-); also elsewhere on the board
LOUT_2: C22.1; also elsewhere on the board
LOUT_2_INTOCN: C24.2, R57.2; also elsewhere on the board
unnamed: C22.2, R23.1, R56.2, U10.3 (+IN)
unnamed: R27.2, R34.1, U10.2 (-IN)
unnamed: R35.1, R36.2, U10.6 (-IN)
unnamed: R27.1, R91.2, U10.1 (OUT)
unnamed: C23.2, R88.1, R89.2, U10.5 (+IN)
unnamed: R36.1, R92.2, U10.7 (OUT)
unnamed: C24.1, R91.1
unnamed: C25.1, R92.1
unnamed: C19.1, L1.P$2, U$9.P$2 (IN+)
ROUT_2: C23.1; also elsewhere on the board
ROUT_2_INTOCN: C25.2, R90.2; also elsewhere on the board

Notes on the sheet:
Buffers the output signal Biased at 2V5
Audio

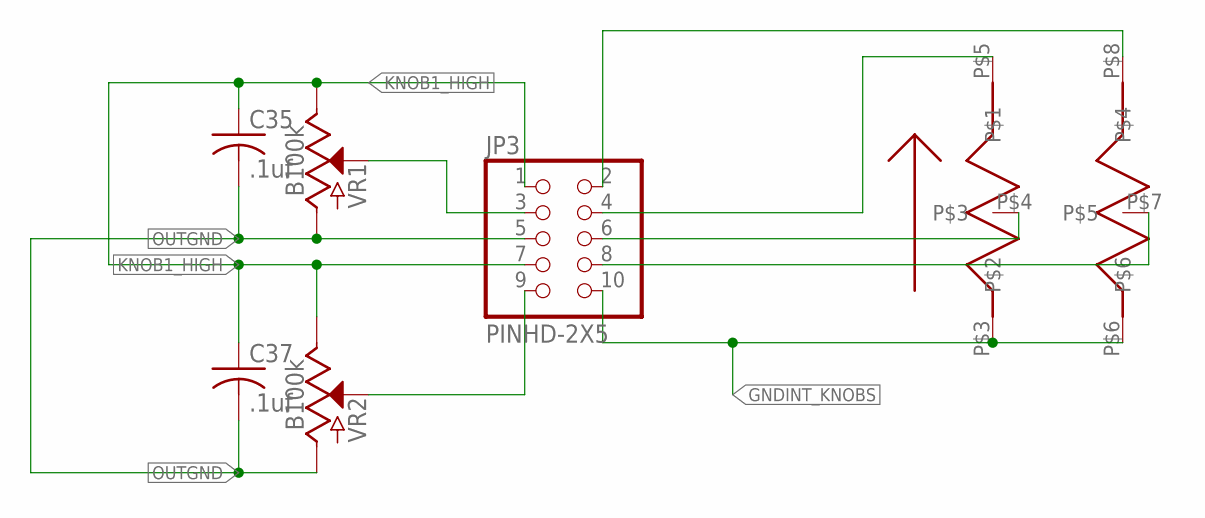
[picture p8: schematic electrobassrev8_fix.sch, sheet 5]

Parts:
C35, C37: .1uf; C0603K; PARTNO CC0603KRX7R8BB104
JP3: PINHD-2X5; 2X05; PARTNO 3020-10-0100-00
U$2: PN092; PARTNO P0925N-FA15AR100K
VR1, VR2: B100k; POT-PTH-ALPS-KIT; PARTNO P0915N-FC15BR100K

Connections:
GNDINT_KNOBS: JP3.10, U$2.P$3, U$2.P$6
KNOB1_HIGH: C35.1, C37.1, JP3.1, JP3.7, VR1.P$1 (E), VR2.P$1 (E)
unnamed: JP3.3, VR1.P$2 (S)
unnamed: JP3.4, U$2.P$5
unnamed: JP3.6, U$2.P$4
unnamed: JP3.9, VR2.P$2 (S)
unnamed: JP3.8, U$2.P$7
unnamed: JP3.2, U$2.P$8
OUTGND: C35.2, C37.2, JP3.5, VR1.P$3 (A), VR2.P$3 (A)

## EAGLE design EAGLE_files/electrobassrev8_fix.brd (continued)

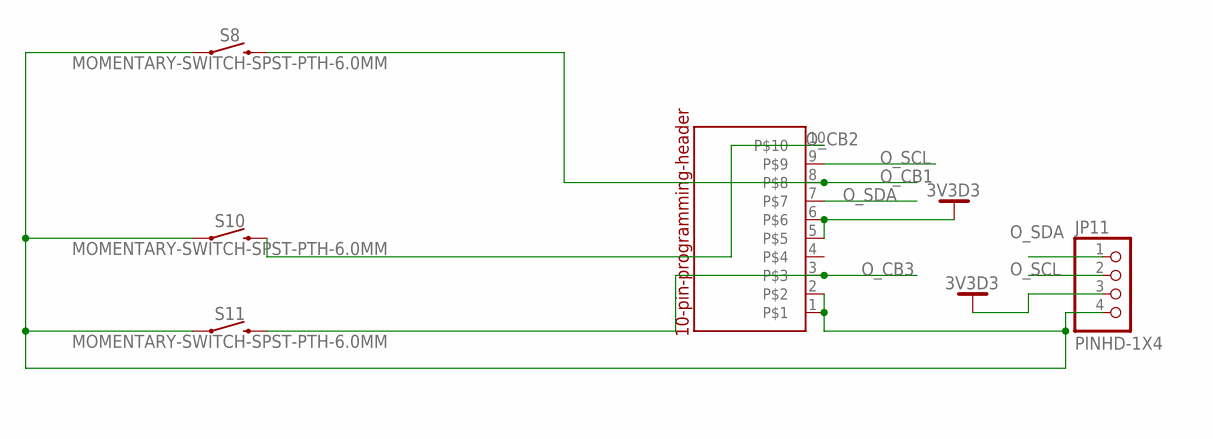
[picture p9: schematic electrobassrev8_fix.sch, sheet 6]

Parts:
JP10: 20021121; PARTNO 3221-10-0300-00
JP11: PINHD-1X4; 1X04; PARTNO *DNP
S8, S10, S11: MOMENTARY-SWITCH-SPST-PTH-6.0MM; TACTILE_SWITCH_PTH_6.0MM; PARTNO TL1105SPF160Q

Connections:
3V3D3: JP10.5, JP10.6, JP11.3
O_CB1: JP10.8, S8.3 (2)
O_CB2: JP10.10, S10.3 (2)
O_CB3: JP10.3, S11.3 (2)
O_GND: JP10.1, JP10.2, JP11.4, S8.1, S10.1, S11.1
O_SCL: JP10.9, JP11.2
O_SDA: JP10.7, JP11.1

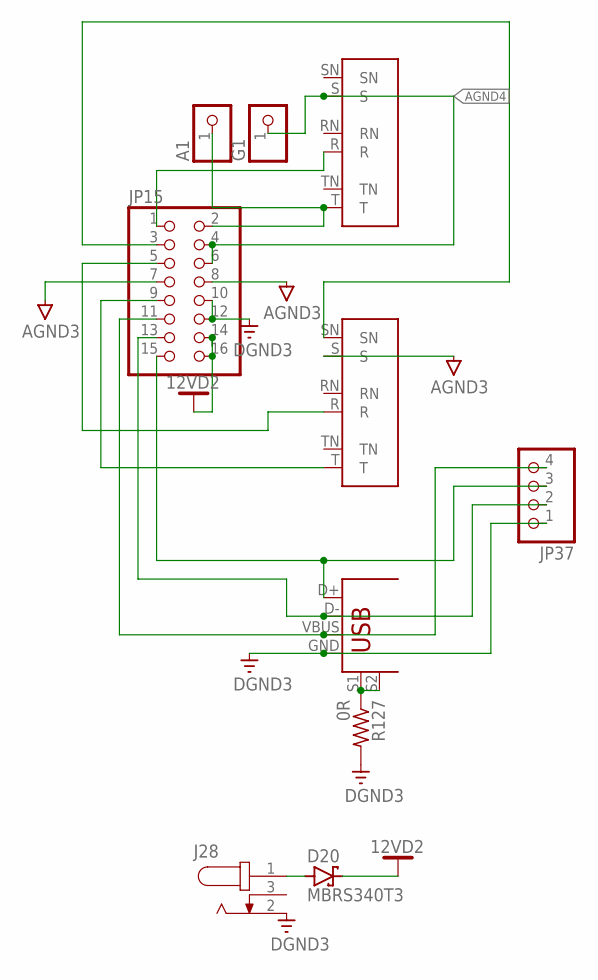
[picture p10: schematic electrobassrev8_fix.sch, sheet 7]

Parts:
A1: PINHD-1X1; 1X01; PARTNO *DNP
D20: MBRS340T3; SMC; PARTNO SS34
G1: PINHD-1X1; 1X01; PARTNO *DNP
J28: PJ-066A; CUI_PJ-066A; PARTNO PJ-066A
JP15: PINHD-2X8; 2X08; PARTNO SBH11-PBPC-D08-ST-BK
JP37: PINHD-1X4; 1X04; PARTNO *DNP
R127: 0R; R0603; PARTNO CRCW06030000Z0EAHP
X2, X3: NRJ6HF2; PARTNO NRJ6HM-1
X4: USB+SHIELD; USB-B-PTH; PARTNO PRT-00139

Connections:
12VD2: D20.C, JP15.14, JP15.16
AGND3: JP15.7, JP15.8, X3.S
AGND4: G1.1, JP15.4, JP15.6, X2.S
DGND3: J28.2, JP15.10, JP15.12, JP37.1, R127.2, X4.GND
unnamed: A1.1, JP15.2, X2.T
unnamed: JP15.5, X3.R
unnamed: JP15.9, X3.T
unnamed: JP15.15, JP37.3, X4.D+
unnamed: JP15.13, JP37.2, X4.D-
unnamed: JP15.11, JP37.4, X4.VBUS
unnamed: D20.A, J28.1
unnamed: JP15.1, X2.R
unnamed: JP15.3, X3.SN
unnamed: R127.1, X4.S1, X4.S2

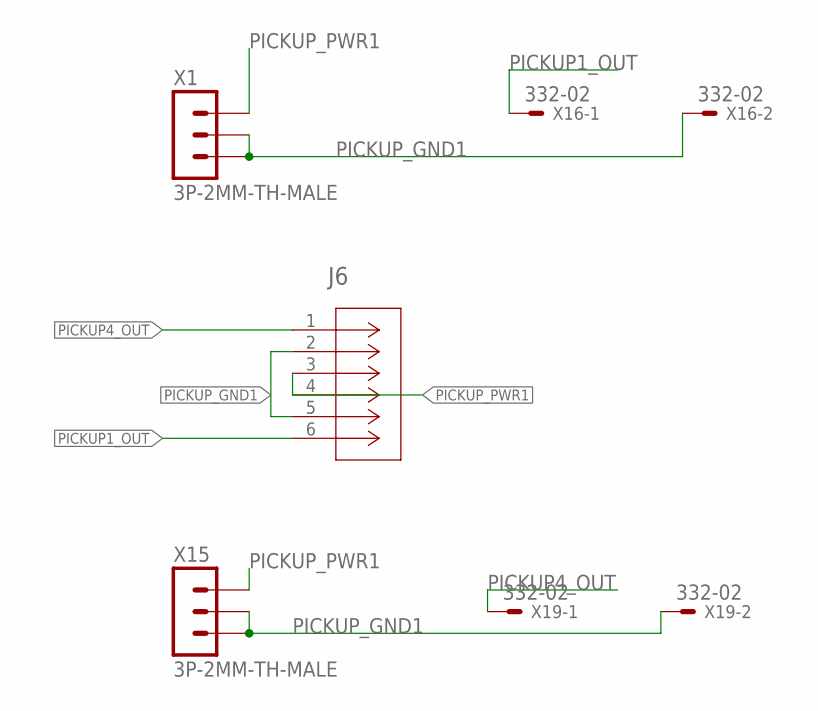
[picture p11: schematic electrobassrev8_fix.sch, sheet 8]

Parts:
J6: SM06B-SRSS-TB(LF)(SN); CONN_SM06B-SRSS-TB_JST
X1, X15: 3P-2MM-TH-MALE; 3P-2MM-TH; PARTNO *DNP
X16, X19: 332-02; PARTNO *DNP

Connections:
PICKUP1_OUT: J6.6, X16.1
PICKUP4_OUT: J6.1, X19.1
PICKUP_GND1: J6.2, J6.5, X1.P$1 (1), X1.P$2 (2), X15.P$1 (1), X15.P$2 (2), X16.2, X19.2
PICKUP_PWR1: J6.3, J6.4, X1.P$3 (3), X15.P$3 (3)

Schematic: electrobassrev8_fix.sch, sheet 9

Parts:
J5: SM06B-SRSS-TB(LF)(SN); CONN_SM06B-SRSS-TB_JST
X13, X14: 3P-2MM-TH-MALE; 3P-2MM-TH; PARTNO *DNP
X17, X18: 332-02; PARTNO *DNP

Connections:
PICKUP2_OUT_HIGH: J5.6, X17.1
PICKUP3_OUT_HIGH: J5.1, X18.1
PICKUP_GND1_HIGH: J5.2, J5.5, X13.P$1 (1), X13.P$2 (2), X14.P$1 (1), X14.P$2 (2), X17.2, X18.2
PICKUP_PWR1_HIGH: J5.3, J5.4, X13.P$3 (3), X14.P$3 (3)

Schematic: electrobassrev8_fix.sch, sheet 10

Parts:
J7, J8: SM06B-SRSS-TB(LF)(SN); CONN_SM06B-SRSS-TB_JST
X5, X6, X7, X8: 332-02; PARTNO *DNP
X9, X10, X11, X12: 3P-2MM-TH-MALE; 3P-2MM-TH; PARTNO *DNP

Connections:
PICKUP1_OUT2: J7.6, X5.1
PICKUP2_OUT2: J8.6, X6.1
PICKUP3_OUT2: J8.1, X7.1
PICKUP4_OUT2: J7.1, X8.1
PICKUP_GND2: J7.2, J7.5, J8.2, J8.5, X5.2, X6.2, X7.2, X8.2, X9.P$1 (1), X9.P$2 (2), X10.P$1 (1), X10.P$2 (2), X11.P$1 (1), X11.P$2 (2), X12.P$1 (1), X12.P$2 (2)
PICKUP_PWR2: J7.3, J7.4, J8.3, J8.4, X9.P$3 (3), X10.P$3 (3), X11.P$3 (3), X12.P$3 (3)

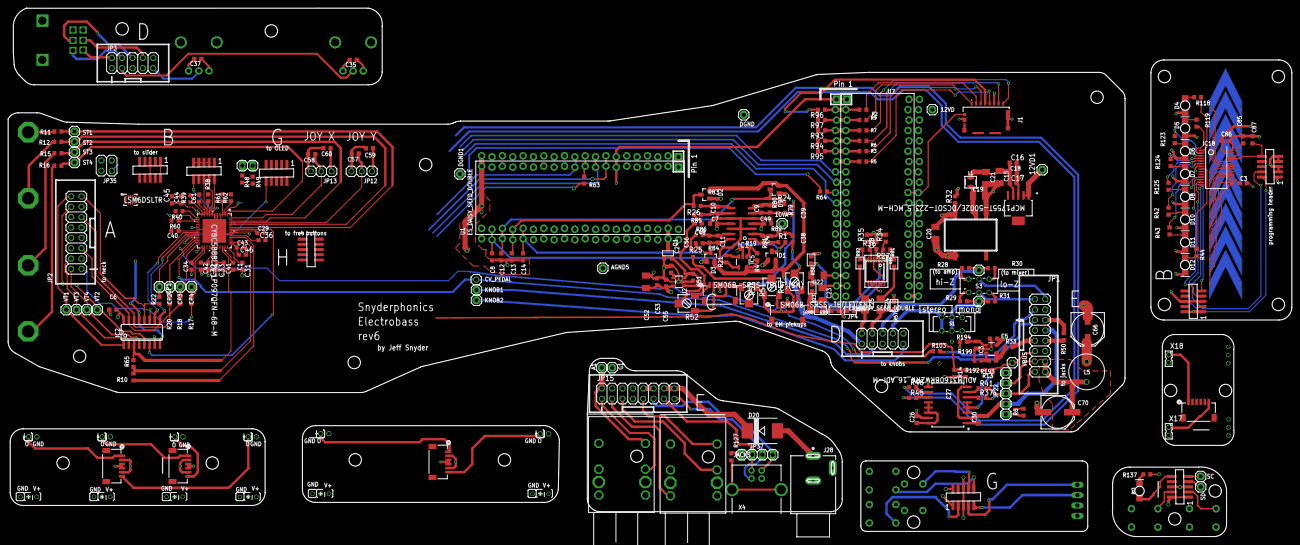
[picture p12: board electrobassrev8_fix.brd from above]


Board: 4 copper layers, 314.7 x 129.5 mm, 283 parts (32 on the bottom side), 245 nets.

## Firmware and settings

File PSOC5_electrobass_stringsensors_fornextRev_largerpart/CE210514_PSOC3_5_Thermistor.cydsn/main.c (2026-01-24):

/*****************************************************************************
* File Name: main.c
*
* Version: 3.0
*
* Description:
*   
* 
* Note:
* 	The main project includes the ADC and other components required for the
*   temperature measurement. The Thermistor component is a complete firmware component
*   as decribed in the component datahseet and application note
******************************************************************************
* Copyright (C) 2015, Cypress Semiconductor Corporation.
******************************************************************************
* This software is prese by Cypress Semiconductor Corporation (Cypress) and is
* protected by and subject to worldwide patent protection (United States and
* foreign), United States copyright laws and international treaty provisions.
* Cypress hereby grants to licensee a personal, non-exclusive, non-transferable
* license to copy, use, modify, create derivative works of, and compile the
* Cypress Source Code and derivative works for the sole purpose of creating
* custom software in support of licensee product to be used only in conjunction
* with a Cypress integrated circuit as specified in the applicable agreement.
* Any reproduction, modification, translation, compilation, or representation of
* this software except as specified above is prohibited without the express
* written permission of Cypress.
*
* Disclaimer: CYPRESS MAKES NO WARRANTY OF ANY KIND, EXPRESS OR IMPLIED, WITH
* REGARD TO THIS MATERIAL, INCLUDING, BUT NOT LIMITED TO, THE IMPLIED
* WARRANTIES OF MERCHANTABILITY AND FITNESS FOR A PARTICULAR PURPOSE.
* Cypress reserves the right to make changes without further notice to the
* materials described herein. Cypress does not assume any liability arising out
* of the application or use of any product or circuit described herein. Cypress
* does not authorize its products for use as critical components in life-support
* systems where a malfunction or failure may reasonably be expected to result in
* significant injury to the user. The inclusion of Cypress' product in a life-
* support systems application implies that the manufacturer assumes all risk of
* such use and in doing so indemnifies Cypress against all charges. Use may be
* limited by and subject to the applicable Cypress software license agreement.
*****************************************************************************/
#include <device.h>
#include <main.h>
#include <stdio.h>
#include "math.h"
#include "oled.h"

#define MAPLE1 1
//#define GREEN3 1

volatile uint8 usbActivityCounter = 0u;
 uint8 midiMsg[4];
volatile uint8_t currentVBUS = 0;
volatile uint8_t prevVBUS = 0;
volatile uint8_t USB_active = 0;
volatile uint8_t USB_check_flag = 0;

uint16_t midiSent = 0;
uint16_t midiOverflow = 0;

uint scanPart = 0;
uint channel = 0;
#define TUNING_ARRAY_SIZE 258
uint8_t tuningArray[TUNING_ARRAY_SIZE];
uint currentOutPointer = 0;
uint outChanged = 0;

void checkUSB_Vbus(void);
void sendMIDIAllNotesOff(void);
void sendMIDIPitchBend(int val, int channel);
void firstCheckUSB_Vbus(void);
void restartSystemCheck(void);
void sendMIDINoteOn(int MIDInoteNum, int velocity, int channel);
void sendMIDIControlChange(int CCnum, int CCval, int channel);
void sendMIDIControlChangeComputer(int CCnum, int CCval, int channel);
CY_ISR_PROTO(SleepIsr_function);
void noteEvent(int string);
void I2C_reset(void);
void CCEvent(int bar);
void scanButtons(void);
void sendCurrentPresetNumber(void);
uint8 I2C_MasterReadBlocking(uint8 i2CAddr, uint16 nbytes, uint8_t mode);

union breakFloat {
 float f;
 uint8_t b[4];  
 uint32_t u32;
};

volatile uint8_t I2Cbuff1[256];
uint8_t stringCapSensorsOnOff[1];
uint8_t stringCapSensorsRaw[16];
uint8_t thresholdArray[8] = {30, 30, 30, 30, 30, 30, 30, 30};
#if MAPLE1
uint32_t fretMeasurements[4][2] = {
    {68958,19847},
    {67974,20532},
    {68984,20665},
    {85647,24651}
};
#elif defined GREEN3
 uint32_t fretMeasurements[4][2] = {
    {75540,22551},
    {64813,19391},
    {63616,19052},
    {71986,21251}
};
#else
uint16_t fretMeasurements[4][2] = {
    {57984,17489},
    {53292,15779},
    {52933,15582},
    {57784,16450}
};
    #endif
float fretRatios[2] = {0.94387439674627617953623675390268f,0.47193719837313808976811837695134f}; 

uint8_t sysexBuffer[1024];
uint32_t sysexPointer = 0;
uint8_t receivingSysex = 0;
uint8_t parsingSysex = 0;
volatile uint8_t presetArray[1024];
uint8_t presetNumberToWrite = 0;
uint8_t sendMessageEnd = 0;
enum presetArraySectionState
{
    presetName = 0,
    initialVals = 2,
    mapCountNext = 3,
    mapping = 4,
    presetEnd = 5,
};
uint8_t presetArraySection = presetName;

uint16_t messageArraySendCount = 0;
uint16_t messageArraySize = 0;

uint8_t sysexMessageInProgress = 0;

int32_t linearPotValue32Bit[4];
uint8_t i = 0;
uint8_t counter = 0;
int32_t temper;
int previousButtons[11];
int octave = 0;
void scanLinearResistor();
int stringPlucks[4];
int stringPlucksPrev[4];

#define KNOB_FIR_SIZE 8
#define KNOB_FIR_SIZE_MASK 7
#define KNOB_FIR_SIZE_BITSHIFT 3
uint32_t knobsFIR[5][KNOB_FIR_SIZE];


#define LINEAR_FIR_SIZE 2
#define LINEAR_FIR_SIZE_MASK 1
#define LINEAR_FIR_SIZE_BITSHIFT 1

float hysteresisStates[4];
float hysteresisLowThresh = 0.4f;
float hysteresisHighThresh = 0.6f;

void DmaTxConfiguration(void);
void DmaRxConfiguration(void);

/* DMA Configuration for DMA_TX */
#define DMA_TX_BYTES_PER_BURST      (1u)
#define DMA_TX_REQUEST_PER_BURST    (1u)
#define DMA_TX_SRC_BASE             (CYDEV_SRAM_BASE)
#define DMA_TX_DST_BASE             (CYDEV_PERIPH_BASE)

/* DMA Configuration for DMA_RX */
#define DMA_RX_BYTES_PER_BURST      (1u)
#define DMA_RX_REQUEST_PER_BURST    (1u)
#define DMA_RX_SRC_BASE             (CYDEV_PERIPH_BASE)
#define DMA_RX_DST_BASE             (CYDEV_SRAM_BASE)

#define BUFFER_SIZE                 (16u)
#define BUFFER_2_SIZE               (16u)
#define STORE_TD_CFG_ONCMPLT        (1u)

/* Variable declarations for DMA_TX*/
volatile uint8 txChannel;
volatile uint8 txTD;
volatile uint8 txBuffer[BUFFER_SIZE];

volatile uint8 rxChannel;
volatile uint8 rxTD;
volatile uint8 rxBuffer[BUFFER_SIZE];

/* Variable declarations for DMA_2*/
volatile uint8 tx2Channel;
volatile uint8 tx2TD;
volatile uint8 tx2Buffer[BUFFER_2_SIZE];

volatile uint8 rx2Channel;
volatile uint8 rx2TD;
volatile uint8 rx2Buffer[BUFFER_2_SIZE];

volatile uint8 tx2BufferTemp[BUFFER_2_SIZE];

    static uint8 CYCODE eepromArray[]={ 0, 0 };
                                            
    uint8 array[] ={ 0, 0 };
                                
    /*Return status for EEPROM and UART*/ 
cy_en_em_eeprom_status_t eepromReturnValue;


/* EEPROM storage in work flash, this is defined in Em_EEPROM.c*/
#if defined (__ICCARM__)
#pragma data_alignment = CY_FLASH_SIZEOF_ROW
const uint8_t Em_EEPROM_em_EepromStorage[Em_EEPROM_PHYSICAL_SIZE] = {0u};
#else
const uint8_t Em_EEPROM_em_EepromStorage[Em_EEPROM_PHYSICAL_SIZE]
__ALIGNED(CY_FLASH_SIZEOF_ROW) = {0u};
#endif /* defined (__ICCARM__) */

    uint8 eeprom_cnt;
    cystatus status;
    volatile const uint8 * ptr;
volatile int barCount = 0;

void handleNotes(int note, int velocity, int string);

int stringStates[4][2] = {{0,0},{0,0},{0,0},{0,0}};

CY_ISR(button_press_ISR) {     /* No need to clear any interrupt source; interrupt component should be      * configured for RISING_EDGE mode.      */     /* Read the debouncer status reg just to clear it, no need to check its      * contents in this application.      */  
 //FiltReg_Read(); 
    //
}

#define INV_440 0.0022727272727273f

float   LEAF_clip(float min, float val, float max)
{
    float tempmin = min;
    float tempmax = max;
    if (min > max)
    {
        tempmin = max;
        tempmax = min;
    }
    if (val < tempmin)
    {
        return tempmin;
    }
    else if (val > tempmax)
    {
        return tempmax;
    }
    else
    {
        return val;
    }
}
float mtof(float f)
{
    if (f <= -1500.0f) return(0);
    else if (f > 1499.0f) return(mtof(1499.0f));
    else return (8.17579891564f * expf(0.0577622650f * f));
}

float ftom(float f)
{
    return (f > 0 ? 17.3123405046f * logf(.12231220585f * f) : -1500.0f);
}

// alpha, [0.0, 1.0]
float LEAF_interpolation_linear (float A, float B, float alpha)
{
    float omAlpha = 1.0f - alpha;
    
    // First 1/2 of interpolation
    float out = A * omAlpha;
    
    out += B * alpha;
    
    return out;
}
void USB_service(void);

volatile int whichLinearSensor = 0;

float map(float value, float istart, float istop, float ostart, float ostop)
{
    return ostart + (ostop - ostart) * ((value - istart) / (istop - istart));
}
uint8 I2C_MasterWriteBlocking(uint8 i2CAddr, uint16 nbytes, uint8_t mode);
void parseSysex(void);
//Main

volatile int testVar = 0;
int lastNotes[4] = {0,0,0,0};
int frettedState = 1;
int polyMode = 0;

float pitchBendsPerString[4];
int openStringCount[4] = {0,0,0,0};
int loudestString = 0;
int64_t timeSinceLastAttack = 0;
float previousHysteresisStates[4] = {0.0f, 0.0f, 0.0f, 0.0f};
float openStringFreqs[4] = {41.203f, 55.0f, 73.416f, 97.999f};
float openStringMIDI[4] = {28.0f, 33.0f, 38.0f, 43.0f};
float invStringMappedPositions[4] = {0,0,0,0};
float stringMIDI[4] = {0,0,0,0};
float stringMIDIPrev[4] = {0,0,0,0};
float linearHysteresis = 0.6f;
float hp_y[4];
float hp_x[4]; 
float hp_R;


int currentPresetSelection = 0;
int highestPresetNumber = MAX_NUM_PRESETS - 1;

uint8_t presetNamesArray[MAX_NUM_PRESETS][14];
uint8_t presetNumberToLoad = 0;
uint8_t presetLoadedResponse[2] = {255, 0};

float vibratoCrossfade[4];
int crossFadeStartCount[4];

int previousPitchBendsSent = 0;
int previousPitchBendsSentPoly[4] = {0};
uint32_t knobs[5];
int buttons;

int firPointer = 0;
uint8_t knobs7bit[5] = {0,0,0,0,0};
uint16_t knobs7bitPrev[5] = {0,0,0,0,0};
uint16_t knobs7bitPrevLS[5] = {0,0,0,0,0};
uint16_t knobs7bitHysteresis = 25;

uint8_t linFirPointer[4] = {0,0,0,0};
uint32_t linearFIR[4][LINEAR_FIR_SIZE];
uint32_t linearSmoothed[4] = {0,0,0,0};
uint32_t linearSmoothedPrev[4] = {0,0,0,0};         
uint32_t LHMuteCounter[4] = {0,0,0,0};
uint8_t LHMute[4] = {0,0,0,0};
uint8_t pitchFreeze[4] = {0,0,0,0};
int32_t pitchBendHistory[4][32];
uint16_t pitchBendHistoryPointer[4] = {0,0,0,0};

int skippedNotes[32][5];
int skipPointer = 0;

uint8_t bufCount = 0;
volatile uint8_t sendingMessage = 0;

uint32_t currentFloat = 0;
uint32_t mapCount = 0;

uint16_t valsCount = 0;
uint16_t mapCountExpectation = 0;
uint16_t numMappings = 0;
volatile uint8_t parseThatMF = 0;
volatile float valCheck = 0.0f;
volatile float testVal = 0.0f;
int buttonCounters[6] = {0,0,0,0,0};
int buttonStates[6] = {0,0,0,0,0};
int frettedStateLatched = 0;
int fretboard_fretless = 1;
uint8_t I2Cbuff2[4];
uint32_t SPI_errors = 0;
/*
CY_ISR(SleepIsr_function)
{
    if (USB_active)
    {
        //check USB activity
        if( USB_CheckActivity() != 0u ) 
        {
            usbActivityCounter = 0u;
        } 
        else 
        {
            usbActivityCounter++;
        }

    }
    //Clear pending interrupt
    SleepTimer_GetStatus();
}
*/
CY_ISR(Vbus_function)
{
    //plug or unplug event
    //check if eeprom has a flag saying you just restarted. If so, don't restart again
    //otherwise, restart
    my_Vbus_ISR_ClearPending();
    vBusPin_ClearInterrupt();
    restartSystemCheck();

}

void restartSystemCheck()
{
    eepromReturnValue = Em_EEPROM_Read(0u, eepromArray, 2u);
    //only do the restart check if there is a USB cable plugged in (to avoid restarting while trying to debug without a usb cable plugged in)
    if (USB_VBusPresent() == 1)
    {
        if (*(volatile uint8 *) &eepromArray[0] == 1u)
        {
            //a flag says we just restarted
            //write a zero so it knows next time that it's OK to restart
            array[0] = 0;
            Em_EEPROM_Write(0u,array,2u);     
            USB_check_flag = 1;
        }
        else
        {
           //otherwise, we need to restart
           array[0] = 1;
           Em_EEPROM_Write(0u,array,2u);  
            USB_Stop();
            I2C_1_Stop();
            CySoftwareReset();
        }
    }
}

int main(void)
{

	CYGlobalIntEnable; 
    while (SPI_ready_Read() == 0)
    {
        ;
    }
    
    //EEPROM_Start();
    
    eepromReturnValue = Em_EEPROM_Init((uint32_t)Em_EEPROM_em_EepromStorage);
    if(eepromReturnValue != CY_EM_EEPROM_SUCCESS)
    {
       // HandleError();
    }
    USB_SetPowerStatus(USB_DEVICE_STATUS_SELF_POWERED);
    my_Vbus_ISR_StartEx(Vbus_function);
    
    if (!USB_VBusPresent())
    {
       restartSystemCheck();
    }
    
    
    IDAC8_1_Start();
	ADC_1_Start();
	AMux_1_Start();
    DmaTxConfiguration();
    DmaRxConfiguration();
    ADC_SAR_Seq_1_Start();
    ADC_SAR_Seq_1_StartConvert();
    SPIM_1_Start();
    SPIM_2_Start();
    I2C_1_Start();
    
    CyDelay(100);
    for (int i = 0; i < MAX_NUM_PRESETS; i++)
    {
        SPIM_2_ClearRxBuffer();
        CyDmaChEnable(rx2Channel, STORE_TD_CFG_ONCMPLT);
        CyDmaChEnable(tx2Channel, STORE_TD_CFG_ONCMPLT);
        //make sure previous SPI2 transmission has completed before transferring the remaining midi date
        while (0u == ((SPIM_2_ReadTxStatus() & SPIM_2_STS_SPI_DONE) || (SPIM_2_ReadTxStatus() & SPIM_2_STS_SPI_IDLE )))
        {
            ;
        }    
        if (rx2Buffer[0] == 253) // message that means audio IC is sending preset names)
        {
            uint8_t whichPresetToName = rx2Buffer[1];
            if (whichPresetToName < MAX_NUM_PRESETS)
            {
                for (int i = 0; i < 14; i++)
                {
                    presetNamesArray[whichPresetToName][i] = rx2Buffer[i+2];
                }
            }
        }
    }
    //I2Cbuff1[0] = 1<<6;
    //status = I2C_MasterWriteBlocking(0x70, 1, I2C_1_MODE_COMPLETE_XFER);
    OLED_init();
    //OLEDwriteInt(0, 5, 0,FirstLine);
    //OLED_draw();
    
    
    CapSense_Start();     
    
    hp_R = 1.0f - (3.14159265358979f * 2.0f * 2.0f / 200.0f);

    CyDelay(10);
    CapSense_InitializeAllBaselines() ;
    
    //SPI_ready_Write(1);
    CyDelay(10);

    //tSimplePoly_init(&myPoly);
	for(;;)
    {


        //turn on the multiplexer channels that set up the resistive sensors
        //#if 0
        ExtMUX_EN_Write(0);
        //CyDelayUs(5);
        scanLinearResistor();

        //now disconnect resistive sensors so that they don't interfere with CapSense
       // #endif
        ExtMUX_EN_Write(1);
        CyDelayUs(5);
        
        scanButtons();
        I2C_MasterReadBlocking(0x8u, 4 ,I2C_1_MODE_COMPLETE_XFER);
        CapSense_ClearSensors();
        CapSense_UpdateEnabledBaselines();
        CapSense_ScanEnabledWidgets();  
        currentOutPointer = 1;
        if (parseThatMF)
        {
            parseSysex();
        }
        if (scanPart == 0)
        {

            //buttons = Status_Reg_1_Read();
            #if 0
            
            
          //  sendMIDIControlChange(whichLinearSensor*3, (linearPotValue32Bit[whichLinearSensor] >> 9) & 127);
          //  sendMIDIControlChange(whichLinearSensor*3+1, (linearPotValue32Bit[whichLinearSensor] >> 2) & 127);
          //  sendMIDIControlChange(whichLinearSensor*3+2, (linearPotValue32Bit[whichLinearSensor] & 3));
            uint8_t fretAbove = binarySearch(fretMeasurements[whichLinearSensor], 0, 21, linearPotValue32Bit[whichLinearSensor]);
            float pitchBendVal = 8192.0;
            float midiFloat = 0.0f;
            if (fretAbove > 0)
            {
                float range = fretMeasurements[whichLinearSensor][fretAbove-1] - fretMeasurements[whichLinearSensor][fretAbove];
                float ratio = ((float)(linearPotValue32Bit[whichLinearSensor]  - fretMeasurements[whichLinearSensor][fretAbove])) / range;
                midiFloat = (1.0f - ratio) + (float)(fretAbove - 1);
            }
            if (frettedState)
            {
                float roundedMidiFloat = roundf(midiFloat);
                if (midiFloat < hysteresisStates[whichLinearSensor] - 0.6f)
                {
                    hysteresisStates[whichLinearSensor] = roundedMidiFloat;   
                }
                else if (midiFloat > hysteresisStates[whichLinearSensor] + 0.6f)
                {
                    hysteresisStates[whichLinearSensor] = roundedMidiFloat;   
                }
                if (hysteresisStates[whichLinearSensor] != previousHysteresisStates[whichLinearSensor])
                {
                    vibratoCrossfade[whichLinearSensor] = 0.0f;
                    crossFadeStartCount[whichLinearSensor] = 0;
                }
                //64 is the number of passes through this loop that it waits before applying the highpassed vibrato
                //otherwise you get glitches as the filter picks up fret changes and smoothes them out
                // would be better to do highpass and lowpass to narrow to bandwidth of 1Hz to 10Hz or so
                else if ((vibratoCrossfade[whichLinearSensor] < 1.5f) && (crossFadeStartCount[whichLinearSensor] > 64))
                {
                    vibratoCrossfade[whichLinearSensor] += 0.01f;
                   
                }
                else if (crossFadeStartCount[whichLinearSensor] <= 64)
                {
                    crossFadeStartCount[whichLinearSensor]++;
                }
         
                previousHysteresisStates[whichLinearSensor] = hysteresisStates[whichLinearSensor];
                                //high pass filter to get fast changes to add later
                float vibrato = midiFloat - hp_x[whichLinearSensor] + hp_R * hp_y[whichLinearSensor];
                hp_x[whichLinearSensor] = midiFloat;
                hp_y[whichLinearSensor] = vibrato;
                
                midiFloat = hysteresisStates[whichLinearSensor]+ (vibrato * vibratoCrossfade[whichLinearSensor]);
            }                
            #endif
            
             
            float pitchBendVal = 8192.0;
            
            //if we have read a "not pressed to fretboard" sensor reading
            if (linearPotValue32Bit[whichLinearSensor] == 65535)
            {
                stringMIDI[whichLinearSensor] = openStringMIDI[whichLinearSensor];
                 //pitchBendVal  = (stringMIDI[whichLinearSensor] * 341.0f) + 8192.0f;
                //if ((openStringCount[whichLinearSensor] < 5) || (CapSense_sensorOnMask[whichLinearSensor] & 1))
                //{
                //    openStringCount[whichLinearSensor]++;
                //}
                //else
                //{
                //    pitchBendsPerString[whichLinearSensor] = pitchBendVal;
               // }
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

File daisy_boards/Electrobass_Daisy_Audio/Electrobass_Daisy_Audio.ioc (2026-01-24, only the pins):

Mcu.UserName=STM32H750IBKx
PA1.Signal=GPIO_Input
PA4.Signal=COMP_DAC11_group
PA5.Signal=COMP_DAC12_group
PB11.Signal=I2C2_SDA
PB12.Signal=GPIO_Output
PB14.Signal=USB_OTG_HS_DM
PB15.Signal=USB_OTG_HS_DP
PB5.Signal=SPI1_MOSI
PB8.Signal=I2C1_SCL
PB9.Signal=I2C1_SDA
PC10.Signal=SDMMC1_D2
PC11.Signal=SDMMC1_D3
PC12.Signal=SDMMC1_CK
PC7.Signal=GPIO_Output
PC8.Signal=SDMMC1_D0
PC9.Signal=SDMMC1_D1
PD0.Signal=FMC_D2_DA2
PD1.Signal=FMC_D3_DA3
PD10.Signal=FMC_D15_DA15
PD14.Signal=FMC_D0_DA0
PD15.Signal=FMC_D1_DA1
PD2.Signal=SDMMC1_CMD
PD8.Signal=FMC_D13_DA13
PD9.Signal=FMC_D14_DA14
PE0.Signal=FMC_NBL0
PE1.Signal=FMC_NBL1
PE10.Signal=FMC_D7_DA7
PE11.Signal=FMC_D8_DA8
PE12.Signal=FMC_D9_DA9
PE13.Signal=FMC_D10_DA10
PE14.Signal=FMC_D11_DA11
PE15.Signal=FMC_D12_DA12
PE2.Signal=SAI1_MCLK_A
PE3.Signal=SAI1_SD_B
PE4.Signal=SAI1_FS_A
PE5.Signal=SAI1_SCK_A
PE6.Signal=SAI1_SD_A
PE7.Signal=FMC_D4_DA4
PE8.Signal=FMC_D5_DA5
PE9.Signal=FMC_D6_DA6
PF0.Signal=FMC_A0
PF1.Signal=FMC_A1
PF10.Signal=QUADSPI_CLK
PF11.Signal=FMC_SDNRAS
PF12.Signal=FMC_A6
PF13.Signal=FMC_A7
PF14.Signal=FMC_A8
PF15.Signal=FMC_A9
PF2.Signal=FMC_A2
PF3.Signal=FMC_A3
PF4.Signal=FMC_A4
PF5.Signal=FMC_A5
PF6.Signal=QUADSPI_BK1_IO3
PF7.Signal=QUADSPI_BK1_IO2
PF8.Signal=QUADSPI_BK1_IO0
PF9.Signal=QUADSPI_BK1_IO1
PG0.Signal=FMC_A10
PG1.Signal=FMC_A11
PG10.Signal=SPI1_NSS
PG11.Signal=SPI1_SCK
PG15.Signal=FMC_SDNCAS
PG2.Signal=FMC_A12
PG3.Signal=GPXTI3
PG4.Signal=FMC_A14_BA0
PG5.Signal=FMC_A15_BA1
PG6.Signal=QUADSPI_BK1_NCS
PG8.Signal=FMC_SDCLK
PH10.Signal=FMC_D18
PH11.Signal=FMC_D19
PH12.Signal=FMC_D20
PH13.Signal=FMC_D21
PH14.Signal=FMC_D22
PH15.Signal=FMC_D23
PH2.Signal=FMC_SDCKE0
PH3.Signal=FMC_SDNE0
PH4.Signal=I2C2_SCL
PH5.Signal=FMC_SDNWE
PH8.Signal=FMC_D16
PH9.Signal=FMC_D17
PI0.Signal=FMC_D24
PI1.Signal=FMC_D25
PI10.Signal=FMC_D31
PI2.Signal=FMC_D26
PI3.Signal=FMC_D27
PI4.Signal=FMC_NBL2
PI5.Signal=FMC_NBL3
PI6.Signal=FMC_D28
PI7.Signal=FMC_D29
PI9.Signal=FMC_D30

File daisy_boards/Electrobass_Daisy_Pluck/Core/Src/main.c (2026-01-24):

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
/* Includes ------------------------------------------------------------------*/
#include "main.h"
#include "adc.h"
#include "dac.h"
#include "dma.h"
#include "i2c.h"
#include "rng.h"
#include "spi.h"
#include "tim.h"
#include "gpio.h"
#include "fmc.h"

/* USER CODE BEGIN Includes */
#include "leaf.h"
/* USER CODE END Includes */

/* USER CODE BEGIN PD */
#define SDRECORD 0
#define SAMPLE_RATE 48000

//#define MAPLE1
#define GREEN3
/* USER CODE END PD */


/* USER CODE BEGIN PV */
volatile uint8_t SPI_TX[32] __ATTR_RAM_D2;
volatile uint8_t SPI_RX[32] __ATTR_RAM_D2;

#define NUM_ADC_CHANNELS 4
#define ADC_FRAME_SIZE 1
#define ADC_BUFFER_SIZE ADC_FRAME_SIZE * 2
#define NUM_STRINGS 4

uint32_t ADC_values[2 * ADC_BUFFER_SIZE] __ATTR_RAM_D2;

#define FILTER_ORDER 1
#define ATODB_TABLE_SIZE 25000
#define ATODB_TABLE_SIZE_MINUS_ONE 24999


#define MEDIUM_MEM_SIZE 300000
char mediumMemory[MEDIUM_MEM_SIZE] __ATTR_RAM_D1;
tMempool mediumPool;


int smoothedInt[NUM_STRINGS];
int smoothedInt2[NUM_STRINGS];
int dbSmoothedInt[NUM_STRINGS];
int tempAbsInt[NUM_STRINGS];
float atodbTable[ATODB_TABLE_SIZE];
int storedMaximums[NUM_STRINGS] = {10000.0f, 10000.0f, 10000.0f, 10000.0f};
float storedMaxFloats[NUM_STRINGS];
volatile uint16_t stringPositions[NUM_ADC_CHANNELS];
volatile uint16_t stringTouchRH[NUM_ADC_CHANNELS];
volatile uint16_t stringTouchRHPrev[NUM_ADC_CHANNELS];
volatile uint16_t stringTouchLH[NUM_ADC_CHANNELS];
volatile int didPlucked[NUM_ADC_CHANNELS];
volatile int stringSounding[NUM_ADC_CHANNELS];

int howManyFrames = 48000;
int brokedIt = 0;
int didPlucked2[4];
int pluckDelay[4];
int pluckValues[4];

float Dsmoothed;
float Dsmoothed2;
float dbSmoothed2;

float stringScaling[4] = {2.0f, 1.3f, 0.9f, 0.4f};
float stringScaling2[4] = {1.20f, 1.4f, 0.9f, 0.5f};
int armed[NUM_STRINGS] = {0,0,0,0};
float prevdbSmoothed2[NUM_STRINGS];
int threshOut = 0;
int stringMaxes[NUM_STRINGS] = {0,0,0,0};
int downCounter[NUM_STRINGS];
int armedCounter[NUM_STRINGS];
float slopeStorage[NUM_STRINGS];


tHighpass opticalHighpass[NUM_ADC_CHANNELS][FILTER_ORDER];
tHighpass EMHighpass[4];
tVZFilter opticalLowpass[NUM_ADC_CHANNELS][FILTER_ORDER];
tSlide fastSlide[NUM_ADC_CHANNELS];
tSlide slowSlide[NUM_ADC_CHANNELS];
tThreshold threshold[NUM_ADC_CHANNELS];
LEAF leaf;
int counter = 0;


/* USER CODE END PV */

void SystemClock_Config(void);
void PeriphCommonClock_Config(void);
/* USER CODE BEGIN PFP */
void MPU_Conf(void);
float randomNumber(void);
/* USER CODE END PFP */

/**
  * @brief  The application entry point.
  * @retval int
  */
int main(void)
{
  /* USER CODE BEGIN 1 */
  MPU_Conf();
  /* USER CODE END 1 */

  /* Enable I-Cache---------------------------------------------------------*/
  SCB_EnableICache();

  /* Enable D-Cache---------------------------------------------------------*/
  SCB_EnableDCache();

  /* MCU Configuration--------------------------------------------------------*/

  /* Reset of all peripherals, Initializes the Flash interface and the Systick. */
  HAL_Init();

  /* Configure the system clock */
  SystemClock_Config();

/* Configure the peripherals common clocks */
  PeriphCommonClock_Config();

  /* Initialize all configured peripherals */
  MX_GPIO_Init();
  MX_DMA_Init();
  MX_ADC1_Init();
  MX_FMC_Init();
  MX_SPI1_Init();
  MX_TIM1_Init();
  MX_I2C1_Init();
  MX_RNG_Init();
  MX_ADC2_Init();
  MX_DAC1_Init();
  /* USER CODE BEGIN 2 */
  //HAL_GPIO_WritePin(GPIOA, GPIO_PIN_0, GPIO_PIN_RESET);
  uint32_t tempFPURegisterVal = __get_FPSCR();
  tempFPURegisterVal |= (1<<24); // set the FTZ (flush-to-zero) bit in the FPU control register
  __set_FPSCR(tempFPURegisterVal);

  while(HAL_GPIO_ReadPin(GPIOC, GPIO_PIN_12) == 0)
  {
	  ;
  }
  for (int i = 0; i < 32; i++)
  {
	  SPI_TX[i] = i;
  }

  for (int i = 0; i < 8; i++)
  {
	  SPI_TX[i] = 0;
  }
  for (int i = 16; i < 24; i++)
  {
	  SPI_TX[i] = 0;
  }


  //HAL_SPI_TransmitReceive_DMA(&hspi1, SPI_TX, SPI_RX, 32);
  HAL_SPI_TransmitReceive_IT(&hspi1, SPI_TX, SPI_RX, 16);
  //HAL_Delay(10);

  LEAF_init(&leaf, SAMPLE_RATE, mediumMemory, MEDIUM_MEM_SIZE, &randomNumber);

  for (int i = 0; i < NUM_ADC_CHANNELS; i++)
  {
  	tThreshold_init(&threshold[i],700.0f, 900.0f, &leaf);//.01 .05
  	tSlide_init(&fastSlide[i],1.0f,500.0f, &leaf); //500
  	tSlide_init(&slowSlide[i],1.0f,700.0f, &leaf); //500 //1000

  	storedMaxFloats[i] = (65535.0f / storedMaximums[i]);
  	for (int j = 0; j < FILTER_ORDER; j++)
  	{
  		tVZFilter_init(&opticalLowpass[i][j], Lowpass, 1000.0f, 0.2f, &leaf); //1000
  		tHighpass_init(&opticalHighpass[i][j], 60.0f, &leaf); //100
  	}
  }
  HAL_DAC_Start(&hdac1, DAC_CHANNEL_1);
  HAL_DAC_Start(&hdac1, DAC_CHANNEL_2);
  LEAF_generate_atodb(atodbTable, ATODB_TABLE_SIZE);
  HAL_ADC_Start(&hadc2);
  HAL_ADCEx_MultiModeStart_DMA(&hadc1,(uint32_t*)&ADC_values,2 * ADC_BUFFER_SIZE);

  /* USER CODE END 2 */

  /* Infinite loop */
  /* USER CODE BEGIN WHILE */
  while (1)
  {
    /* USER CODE END WHILE */

    /* USER CODE BEGIN 3 */

	  //HAL_GPIO_WritePin(GPIOC, GPIO_PIN_7, GPIO_PIN_SET);

	  HAL_Delay(100);

	  //HAL_GPIO_WritePin(GPIOC, GPIO_PIN_7, GPIO_PIN_RESET);
  }
  /* USER CODE END 3 */
}
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

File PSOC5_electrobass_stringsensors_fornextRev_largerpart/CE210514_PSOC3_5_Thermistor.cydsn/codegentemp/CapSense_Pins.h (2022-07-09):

/*******************************************************************************
* File Name: CapSense_Pins.h
* Version 3.50
*
* Description:
*  This file contains API to enable firmware control of a Pins component.
*
* Note:
*  None
*
********************************************************************************
* Copyright 2008-2013, Cypress Semiconductor Corporation.  All rights reserved.
* You may use this file only in accordance with the license, terms, conditions,
* disclaimers, and limitations in the end user license agreement accompanying
* the software package with which this file was provided.
*******************************************************************************/

#if !defined(CY_CAPSENSE_CSD_Pins_CapSense_H)
#define CY_CAPSENSE_CSD_Pins_CapSense_H

#include "cytypes.h"
#include "cyfitter.h"
#include "cypins.h"
#include "CapSense.h"


/***************************************
*        Function Prototypes
***************************************/

void CapSense_SetAllSensorsDriveMode(uint8 mode) ;
void CapSense_SetAllCmodsDriveMode(uint8 mode) ;
#if (CapSense_CURRENT_SOURCE == CapSense_EXTERNAL_RB)
    void CapSense_SetAllRbsDriveMode(uint8 mode) ;    
#endif  /* (CapSense_CURRENT_SOURCE == CapSense_EXTERNAL_RB) */   


/***************************************
*           API Constants        
***************************************/

/* Drive Modes */
#define CapSense_DM_ALG_HIZ         (PIN_DM_ALG_HIZ)
#define CapSense_DM_DIG_HIZ         (PIN_DM_DIG_HIZ)
#define CapSense_DM_RES_UP          (PIN_DM_RES_UP)
#define CapSense_DM_RES_DWN         (PIN_DM_RES_DWN)
#define CapSense_DM_OD_LO           (PIN_DM_OD_LO)
#define CapSense_DM_OD_HI           (PIN_DM_OD_HI)
#define CapSense_DM_STRONG          (PIN_DM_STRONG)
#define CapSense_DM_RES_UPDWN       (PIN_DM_RES_UPDWN)

/* PC registers defines for sensors */
#define CapSense_PortCH0__Button0__BTN  CapSense_PortCH0__Button0__BTN__PC
#define CapSense_PortCH0__Button1__BTN  CapSense_PortCH0__Button1__BTN__PC
#define CapSense_PortCH0__Button2__BTN  CapSense_PortCH0__Button2__BTN__PC
#define CapSense_PortCH0__Button3__BTN  CapSense_PortCH0__Button3__BTN__PC
#define CapSense_PortCH1__Button4__BTN  CapSense_PortCH1__Button4__BTN__PC
#define CapSense_PortCH1__Button5__BTN  CapSense_PortCH1__Button5__BTN__PC
#define CapSense_PortCH1__Button6__BTN  CapSense_PortCH1__Button6__BTN__PC
#define CapSense_PortCH1__Button7__BTN  CapSense_PortCH1__Button7__BTN__PC
/* For Cmods*/
#define CapSense_CmodCH0_Cmod_CH0       CapSense_CmodCH0__Cmod_CH0__PC
#define CapSense_CmodCH1_Cmod_CH1       CapSense_CmodCH1__Cmod_CH1__PC


#endif /* (CY_CAPSENSE_CSD_Pins_CapSense_H) */


/* [] END OF FILE */

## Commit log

2022-07-07 Replace old folder with
    [Electrobass_Daisy_Audio.ioc, main.c]
2022-07-07 added eagle files
    [electrobassrev5b.brd, electrobassrev5b.sch, electrobassrev6.brd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]
2022-07-09 updated spi in psoc code
    [CE210514_PSOC3_5_Thermistor.sdf]
2022-07-10 receiving spi messages on audio board
2022-07-11 audio board receives and parses midi - amplitude of resulting note is not scaled correctly compared with detected amplitude
    [main.c]
2022-07-12 Fix Order of Operations in velocity code
    [main.c]
2022-07-12 adjusted pluck detection parameters, might be too slow now but will give accurate amplitude
    [Electrobass_Daisy_Pluck.ioc, main.c]
2022-07-12 velocity changes
2022-07-16 getting midi sysex preset data and sending to STM32
    [CE210514_PSOC3_5_Thermistor.sdf]
2022-07-27 bootloader sram working
    [Daisy_Seed_Rev4_Pinout.csv]
2022-08-01 working custom bootloader with debug capability
    [Daisy_Seed_Rev4_Pinout.csv, Electrobass_Daisy_Audio.cfg, Electrobass_Daisy_Bootloader.cfg]
2022-08-11 fixed spi overflow bug and worked on preset sending
    [CE210514_PSOC3_5_Thermistor.sdf]
2022-08-11 continuing bootloader work - further but still broken
    [Electrobass_Daisy_Audio.ioc, main.c]
2022-08-16 fixed bootloader mostly - changed priority of spi and audio and changed direction of spi ready pin
    [electrobassrev7_fix.brd, electrobassrev7_fix.sch]
2022-08-16 changed SPI ready pin to go from audio IC to brain IC rather than other way around
    [CE210514_PSOC3_5_Thermistor.sdf, Electrobass_slider.sdf]
2022-08-17 added cycle counting and fixed many bugs including mapping destination pointers
    [main.c]
2022-08-17 added 255 sending for mappings without scalar
    [CE210514_PSOC3_5_Thermistor.sdf]
2022-08-17 changed how mapping works to sum after real values, but still needs fixing to properly handle bipolar sources
    [Electrobass_Daisy_Audio.ioc, main.c]
2022-08-18 finally fixed things so that it properly reads preset on power up and writes presets with much less chance for error. still got one bug in a long session of writing presets, but much better
    [main.c]
2022-08-18 edited cStack to be a three element buffer, and set up SPI to not parse midi but rather leave that to audio frame
2022-08-22 changed the way that preset sysex is parsed to be more reliable
    [CE210514_PSOC3_5_Thermistor.sdf]
2022-08-22 improved USB DMA handling
    [CE210514_PSOC3_5_Thermistor.sdf]
2022-08-23 adjusted audio board to take new preset input format, and fixed harmonic divider not working
    [main.c]
2022-08-24 new combo saw and pulse oscillator for better efficiency, and doubled bipolar mapping amounts
    [main.c]
2022-08-24 fixed bootloader ARM MATH bug
2022-08-25 fixing LFO stuff and taking away range clipping on frequency. also added smoothing on mappings
    [main.c]
2022-08-25 added lfoOn flags to avoid ticking LFOs that are not used. might be a better idea to just point shapeTick to a blank function.
    [main.c]
2022-08-26 adjusted MPU settings to make more sense for executing from SRAM and to prevent speculative fetch from external memories SDRAM and QSPI
    [main.c]
2022-08-30 removed old zip file
    [CE210514_PSOC3_5_Thermistor.sdf]
2022-09-06 changes to how presets are loaded
    [electrobassrev8_fix.brd, electrobassrev8_fix.sch]
2022-09-15 adjusted things on psoc to improve touch sensing and pluck timing, and to make left hand mutes allow short notes
    [CE210514_PSOC3_5_Thermistor.sdf]
2022-09-23 Add Tuning Send
    [CE210514_PSOC3_5_Thermistor.sdf]
2022-10-08 added fretted and fretless buttons
2022-10-14 writing multiple presets to an sd card and loading them based on commands from psoc
    [electrobassrev8_fix.brd, electrobassrev8_fix.sch]
2022-10-14 psoc preset naming and loading
    [CE210514_PSOC3_5_Thermistor.sdf]
2022-12-15 slightly edited filter code to remove bw things and replaced some rounds with comparisons
    [main.c]
2023-01-17 updated eagle file for rev9 fix
    [electrobassrev9_fix.brd, electrobassrev9_fix.sch]
2023-02-24 fixed reading of new presets from plugin to align with electrosteel
    [electrobassrev9_fix.brd, electrobassrev9_fix.sch]
2023-02-24 fixed things to load presets, removed need to press enter for preset loading
    [CE210514_PSOC3_5_Thermistor.sdf, Electrobass_slider.sdf]
2023-03-17 pushing before pull
    [CE210514_PSOC3_5_Thermistor.sdf]
2023-03-17 greatly improved pluck detection, no longer relies on falling edge of touch sensor
    [main.c]
2023-03-17 added vibrato back in and tightened criteria for ignored notes based on better pluck detection
    [CE210514_PSOC3_5_Thermistor.sdf]
2023-03-18 changed fretboard sensor to 12 bit for speed
    [CE210514_PSOC3_5_Thermistor.sdf]
2023-03-18 subtle tweaks to threshold and slope detector values to improve quiet note detection and accidental re-attack. should possibly add a little code to send a note off before note on in case of purposefu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
2023-03-18 worked on behavior when pulling off note, ended up with only one sample delay of linear sensor, sped up linear sensing so that it is every cycle rather than every 4
2023-03-20 more tweaking of attack pluck stuff. Also discovered that pluck data was being sent 4 transmissions late, so removed DMA from SPI communication
2023-03-20 added error checking on communication with pluck IC, and tuned parameters of capsensors
    [CE210514_PSOC3_5_Thermistor.sdf]
2026-03-05 not sure
    [CE210514_PSOC3_5_Thermistor.sdf]

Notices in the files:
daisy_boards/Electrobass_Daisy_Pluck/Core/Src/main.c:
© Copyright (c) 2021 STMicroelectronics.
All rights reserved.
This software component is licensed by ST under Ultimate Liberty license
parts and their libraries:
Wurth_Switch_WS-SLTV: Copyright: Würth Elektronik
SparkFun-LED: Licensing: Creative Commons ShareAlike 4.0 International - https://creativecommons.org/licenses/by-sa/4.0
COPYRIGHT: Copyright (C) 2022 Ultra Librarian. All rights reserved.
